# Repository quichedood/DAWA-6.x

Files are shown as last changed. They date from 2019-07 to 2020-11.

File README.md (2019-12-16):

# DAWA-6.x - FR (See below for US)

Site web officiel (FR) : http://dawa.panik-po.com/

DAWA est un système de chronométrage et d'acquisition de données pour votre moto.
Il enregistre les données 10x par seconde dans un fichier CSV.

# Q&A rapide
* __Comment sont récupérées les données ?__  
Pas de prise OBD, protocole trop lent sur ma "veille" moto de 2009. Je récupère les informations directement sur le faisceau du calculateur.
Chaque moto est différente, il faudra sur une autre moto :
    - Identifier les signaux (RPM, vitesse, position poignée de gaz, rapport engagé et frein)
    - Vérifier la forme des signaux (RPM = signal carré, poignée de gaz = signal analogique, etc.)
    - Eventuellement adapter le code au niveau de la programmation si le signal est complètement différent

* __Je peux l'assembler moi même ?__  
Aucun problème, attention néanmoins, il vous faut au minimum :
    - Le circuit imprimé (je peux le fournir, j'en ai quelques uns en stock)
    - Un programmateur pour les 2 µproc Atmel SAMD21 (Atmel ICE BASIC par exemple)
    - Une station de soudure à l'air chaud (indispensable pour souder l'IMU)

* __Combien ça coute ?__  
Grossièrement, voici ce que ça me coûte :
    - PCB : ~10€
    - Composants : ~90€
    - Autres (impression 3D, résine pour les sondes de t°, la journée passée à assembler un exemplaire) : à vous de juger

Certes, ça reste moins cher que ce que l'on peut trouver dans le commerce (Starlane, Alfano, 3DMS) mais ce n'est clairement pas comparable.  
Vous voulez un vrai chrono, utilisable à la sortie de sa boite, passez votre chemin et dirigez vous vers les produits du commerce.  
Vous voulez un maximum de fonctionnalités, pouvoir faire évoluer un projet libre et avez quelques notions en électronique/développement, ce projet est pour vous :)

# Les nouveautés de la v6
* __Nouveau circuit imprimé__ : DAWA v6 est désormais un circuit imprimé autonome (puce Atmel SAMD21 comme l'Arduino M0). La v5 était un module qui se branchait sur un Arduino M0
* __Nouveau capteur de position__ : Le capteurs 9 axes MPU-9250 est maintenant utilisé. Ce capteur est monté sur un circuit imprimé secondaire avec son propre µproc (Atmel SAMD21)
* __Nouvel écran OLED__ : Un peu plus grand (1.3" vs 0.96"). Le connecteur d’écran (SPI) est compatible avec les écrans LCD couleur 2,4" 240x320
* __Nouveau boitier__ : Un tout nouveau boîtier imprimé en 3D
* __Autodetection des capteurs__ : Les capteurs de température infrarouges sont maintenant détectés automatiquement
* __Navigation__ : Ajout d'un système de menu de navigation et 4 boutons pour permettre la configuration et l'utilisation sans smartphone ni Bluetooth
* __LEDs__ : Ajout de 4 LEDs pour des événements spécifiques (meilleur temps au tour par exemple)
* __Connecteurs__ : tous les connecteurs sont maintenant du même côté (en bas), le connecteur GPS est maintenant de type SMA (à visser)
* __Batterie GPS__ : Batterie rechargeable LIR 2025

# Quelles informations sont enregistrées ?
* __Acquisition de données bruts__ : Sur les motos Triumph et beaucoup d’autres, les valeurs du calculateur peuvent être lues directement (j’utilise personnellement: RPM, vitesse, position poignée de gaz, rapport engagé et frein)
* __Atitude de la moto__ : Un capteur à 9 axes (MPU-9250) est utilisé pour stocker les G et j'espère que bientôt, le roulis et le tangage
* __Position de la moto__ : Une puce GPS UBLOX 10Hz récupère les coordonnées GPS en temps réel
* __Température infrarouge__ : Vous pouvez brancher jusqu'à 6 capteurs de température infrarouge (pneus ou t° au sol, par exemple).
* __Entrées additionnelles__ : Vous pouvez mesurer 2 entrées analogiques et 2 entrées numériques supplémentaires (capteurs de suspension par exemple)

# Où est-ce enregistré ?
Tout est stocké sur une carte micro SD.  
10 fois par seconde, une nouvelle ligne est créée dans un fichier CSV. Cette ligne contient toutes les valeurs de données séparées par un point-virgule.  
Les valeurs actuelles sont affichées en temps réel sur l’écran OLED joint.

# Peut-il être utilisé comme un chronomètre ?
OUI ! Depuis la v4 et l'intégration d'une puce GPS 10Hz, des fonctions de chronométrage sont disponibles.

# Comment ça marche ?
Rien de plus simple !  
Un bouton pour démarrer l'enregistrement et un pour l'arrêter :)  
Un fichier CSV est créé à chaque nouvel enregistrement.  

# Qu'en est-il des fonctions de chronométrage
Un peu plus compliqué, vous devez mettre un fichier nommé "TRACKS.CSV" sur la carte SD.  
Ce fichier contiendra le nom du circuit et les coordonnées de la ligne d'arrivée, une ligne par circuit:  
`<trackname>;<finishline lat. A>;<finishline lon. A>;<finishline lat. B>;<finishline lon. B>`  
`CAROLE;489799930;25224350;489800230;25226330`  
Pour conserver la précision, la latitude et la longitude doivent être converties en nombres entiers (multiplier par 10 000 000).  
Au début de l’enregistrement, la piste la plus proche est automatiquement choisie.

# Vous avez dit Bluetooth?
La connexion Bluetooth est utile dans ces 2 cas:  
- Vous venez de terminer votre session sur piste et vous voulez connaître les temps/meilleurs tours  
- Avant d'utiliser DAWA, certains paramètres peuvent être ajustés, utilisez la console Bluetooth pour les configurer !  
  
J'utilise "Serial Bluetooth Terminal" sur Androïd. Connectez-vous et tapez "help" pour voir toutes les commandes disponibles

# Evolutions
* __Temps intermédiaire__ : Ajout de la gestion des temps intermédiaires

# Bugs connus
* __Angle d'inclinaison__ : Le composant est présent, l'algorithme aussi mais les valeurs dérivent dans le temps. C'est une problématique récurrente.

# Contenu du référentiel
* /3D Case - Pièces Fusion 360 et fichiers STL pour l'impression 3D
* /Arduino - Le fichier .ino que vous devez insérer dans l’Arduino M0
* /Documentation - Quelques informations sur ce projet (FR)
* /Eagle - Tous les fichiers Eagle (schémas, PCB/Gerber, bibliothèques, liste de composants)

# DAWA-6.x - US

French official website project : http://dawa.panik-po.com/

DAWA is an Arduino datalogger and laptimer for your motorbike.
It records 10 times per seconds in a CSV file lots of information.

# What's new in v6
* __New PCB__ : DAWA v6 is now a standalone PCB (Atmel SAMD21 chip like Arduino M0). v5 was a shield which needs an Arduino M0
* __New IMU__ : MPU-9250 is now used. This IMU is on a secondary PCB with his own µproc (Atmel SAMD21)
* __New OLED screen__ : A little bit bigger (1.3" vs 0.96"). The screen connector (SPI) is compatible with 2.4" 240x320 color LCD
* __New enclosure__ : A brand new 3D printed enclosure
* __Sensors autodetection__ : Infrared temperature sensors are now autodetected
* __Navigation__ : Add a navigation menu system and 4 buttons to allow configuration and use without smartphone and Bluetooth
* __Lights__ : Add 4 LEDS for specific events (best time on lap for example)
* __Connectors__ : All connectors are now on the same side (bottom), GPS connector is now SMA
* __GPS battery__ : Rechargeable LIR 2025 Battery

# What information is logged ?
* __Raw data acquisition__ : On Triumph bikes and many others, ECU values can be directly read (I personnaly use : RPM, SPEED, GEAR POSITION, THROTTLE and BRAKE state)
* __Environement values__ : A 9-axis sensor (MPU-9250) is used to store G-forces and I hope soon, roll and pitch
* __Position values__ : A UBLOX 10Hz GPS chip gets realtime coordinates
* __Infrared temperatures__ : You can plug up to 6 infrared temperature sensors (tyres or ground t° for example)
* __Additional inputs__ : You can measure 2 analog inputs and 2 digital inputs (suspension sensors for exemple)

# Where is it logged ?
Everything is stored on a micro SD card.  
10 times per seconds, a new line is created in a CSV file. This line contains every data values separated by a semicolon.  
Current values are displayed in realtime on the OLED screen attached.

# Could it be used as a laptimer ?
YES ! Since v4 and the integration of a 10Hz GPS chip, laptimer functions are available.

# How does it work ?
I couldn't make it easier !  
Press the button start recording, press again stop recording :)  
One CSV file is created on each new record.

# What about laptimer functions
A little bit more difficult, you have to put a file named "TRACKS.CSV" on the sdcard.  
This file will contain track name and finishline coordinates, one line per track :  
`<trackname>;<finishline lat. A>;<finishline lon. A>;<finishline lat. B>;<finishline lon. B>`  
`CAROLE;489799930;25224350;489800230;25226330`  
To keep precision, latitude and longitude should be converted to integers (multiply by 10 000 000).  
When start recording the closer track is automatically chosen.

# You said Bluetooth ?
Bluetooth connection is usefull in these 2 cases :
- You just finish your track session and want to know lap times / best lap
- Before using DAWA, some parameters could be adjusted, use the bluetooth console to setup them !

I'm using "Serial Bluetooth Terminal" on Androïd. Connect and type "help" to view all available commands

# What's next  
* __Laptimer split time__ : Add split time management

# Known bugs
* __Lean angle__ : Seems easy but in fact very complicated to obtain good values without drift

# Repository Contents
* /3D Case - Fusion 360 parts and STL files for 3D printing
* /Arduino - The .ino file you need to put in the Arduino M0
* /Documentation - Some brief explanations about this shield (french - not translated)
* /Eagle - All Eagle files (schematics, PCB/Gerber, libraries, parts list)

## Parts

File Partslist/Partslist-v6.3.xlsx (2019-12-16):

Qty | Value | Device | Package | Parts (Main boards) | Parts (MPU) | Description | Supplier | URL (for example) | Buy price (incl. Shipping) | Buy Qty | Unit Price | Total price
2 | MLX90614 BCC | MLX90614 BCC | TO-39 | MLX90614 BCC |  | Melexis IR Thermometer | ALIEXPRESS | https://www.aliexpress.com/item/32687163490.html?spm=a2g0o.cart.0.0.6e973c008PnrMs | 7.57 | 1 | 7.57 | 15.14
1 | UG-2864HSWEG01 | UG-2864HSWEG01 | 1X30-0.7MM | U$16 |  | UG-2864HSWEG01 OLED display | ALIEXPRESS | https://www.aliexpress.com/item/32955009400.html?spm=a2g0s.9042311.0.0.316a6c37wDnOT8 | 3.12 | 1 | 3.12 | 3.12
1 | NEO-M8 | NEO-M8 | NEO-M8 | U$3 |  | u-blox NEO GNSS module | ALIEXPRESS | https://www.aliexpress.com/item/32822645110.html?spm=a2g0s.9042311.0.0.27424c4dBywEPY | 14.64 | 1 | 14.64 | 14.64
2 | SN74LVC2G17DBVR | SN74LVC2G17DBVR | SOT95P280X145-6N | U12, U13 |  | DUAL SCHMITT-TRIGGER BUFFER | ALIEXPRESS | https://www.aliexpress.com/item/32955292314.html?spm=a2g0o.cart.0.0.55563c00YwAhGV | 9.76 | 50 | 0.1952 | 0.3904
4 | 10µF | CPOL-EUSMCB | SMC_B | C27, C29, C41 | C4 | POLARIZED CAPACITOR, European symbol | MOUSER | https://www.mouser.fr/ProductDetail/581-TAJB106K025RNJ | 0.407 | 1 | 0.407 | 1.628
1 | Power connector | NOT ON PCB | NOT ON PCB | NOT ON PCB |  |  | ALIEXPRESS | https://www.aliexpress.com/item/32820917628.html?spm=a2g0s.9042311.0.0.27424c4diOwAsr | 1.43 | 2 | 0.715 | 0.715
2 | OSCILLATOR_32KHZ | OSCILLATOR_32KHZ | OSCILLATOR_SMD | U$1, U$14 |  | CM7V-T1A Tuning Fork Crystal 32.768 kHz | MOUSER | https://www.mouser.fr/ProductDetail/428-200458-MG01 | 0.385 | 1 | 0.385 | 0.77
1 | GPS antenna | NOT ON PCB | NOT ON PCB | NOT ON PCB |  |  | ALIEXPRESS | https://www.aliexpress.com/item/32631796141.html?spm=a2g0s.9042311.0.0.27424c4d7JbT8R | 2.69 | 1 | 2.69 | 2.69
14 | 4.7k | R-EU_R0603 | R0603 | R13, R17, R18, R21, R22, R25, R49, R50 | R3, R4, R7, R8 | RESISTOR, European symbol | ALIEXPRESS | * | 1 | 100 | 0.01 | 0.14
4 | SKPMAPE10 | SKPMAPE10 | SKPMAPE10 | U$5, U$6, U$7, U$8 |  | Softtouch buttons | ALIEXPRESS | https://www.aliexpress.com/item/32704068968.html?spm=a2g0s.9042311.0.0.68254c4dGCYlrO | 2.26 | 10 | 0.226 | 0.904
5 | P82B96D | P82B96D | SOIC127P600X175-8N | U5, U9, U10 | U3 | DUAL BIDIRECTIONAL BUS BUFFER | ALIEXPRESS | https://www.aliexpress.com/item/32913502650.html?spm=a2g0s.9042311.0.0.27424c4dXN6ine | 15.16 | 20 | 0.758 | 3.79
1 | ATSAMD51G19A_TQFN48 | ATSAMD51G19A_TQFN48 | TQFN-48 |  | U1 | Atmel SAMD51G19A SMART ARM-Based Microcontroller | MOUSER | https://www.mouser.fr/ProductDetail/556-ATSAMD51G19AMUT | 10.77 | 3 | 3.59 | 3.59
1 | MS5637_MS5637 | MS5637_MS5637 | MS5637_MS5637 |  | U4 | Barometric sensor | MOUSER | https://www.mouser.fr/ProductDetail/824-MS563702BA03-50 | 10.9 | 5 | 2.18 | 2.18
2 | MCP23017SS | MCP23017SS | SSOP28 | IC1, IC6 |  |  | MOUSER | https://www.mouser.fr/ProductDetail/579-MCP23017-E-SS | 1.13 | 1 | 1.13 | 2.26
1 | HM-11 | HM-11 | HM-11 | U$2 |  | JNHuaMao HM-11 Bluetooth 4.0 Transceiver | ALIEXPRESS | https://www.aliexpress.com/item/32228842714.html?spm=a2g0s.9042311.0.0.27424c4d7JbT8R | 4.16 | 1 | 4.16 | 4.16
1 | SMA connector | SMACONNECTOR_EDGE | SMA_EDGELAUNCH | X1 |  | SMA Connector | ALIEXPRESS | https://www.aliexpress.com/item/32779564868.html?spm=a2g0s.9042311.0.0.27424c4d7JbT8R | 1.72 | 10 | 0.172 | 0.172
2 | 24AA02E48 | 24AA00OT | SOT23-5L | IC3 | IC1 | Serial EEPROM | MOUSER | https://www.mouser.fr/ProductDetail/579-24AA02E48TIOT | 0.198 | 1 | 0.198 | 0.396
2 | Micro USB connector | USB | USB-MINIB-DAWA | CN1 | CN1 | USB Connectors | ALIEXPRESS | https://www.aliexpress.com/item/32694652292.html?spm=a2g0s.9042311.0.0.27424c4d0a2JnM | 0.82 | 20 | 0.041 | 0.082
1 | LM2734Y | LM2734Y | SOT23-6 | IC2 |  |  | ALIEXPRESS | https://www.aliexpress.com/item/32790388586.html?spm=a2g0s.9042311.0.0.27424c4dXyVsTd | 3.56 | 10 | 0.356 | 0.356
1 | MCP73831/OT | MCP73831/OT | SOT23-5L | IC5 |  | MCP73831/2 | ALIEXPRESS | https://www.aliexpress.com/item/32945891297.html?spm=a2g0s.9042311.0.0.27424c4dlCWdv3 | 2.59 | 20 | 0.1295 | 0.1295
1 | LMV321M5 | LMV321M5 | SOT23-5 | IC7 |  | General Purpose, Low Voltage, Rail-to-Rail Output Operational Amplifiers | MOUSER | https://www.mouser.fr/ProductDetail/926-LMV321M5X-NOPB | 0.716 | 1 | 0.716 | 0.716
2 | PINHEAD_PINHD-2X5PASSO127 | PINHEAD_PINHD-2X5PASSO127 | PINHEAD_2X05_127 | JTAG | JTAG1 | PIN HEADER | ALIEXPRESS | https://www.aliexpress.com/item/32795241952.html?spm=a2g0s.9042311.0.0.27424c4dXyVsTd | 7.17 | 100 | 0.0717 | 0.1434
3 | MH2029-300Y | WE-CBF_0805 | 0805 | L1, L6 | L3 | SMD EMI Suppression Ferrite Beads | MOUSER | https://www.mouser.fr/ProductDetail/652-MH2029-300Y | 0.049 | 1 | 0.049 | 0.147
1 | 27nH | L_0603 | L0603 | L2 |  | INDUCTOR | MOUSER | https://www.mouser.fr/ProductDetail/81-LQG18HN27NJ00D | 0.158 | 1 | 0.158 | 0.158
1 | 10u SRR0604-100ML | L-USSRR0604 | SRR0604 | L4 |  | INDUCTOR, American symbol | MOUSER | https://www.mouser.fr/ProductDetail/652-SRR0604-100ML | 0.473 | 1 | 0.473 | 0.473
1 | PCB kit | NOT ON PCB | NOT ON PCB | NOT ON PCB |  | All PCB for DAWA (2 infrared temperature sensor) | JLCPCB | N/A | 104 | 10 | 10.4 | 10.4
2 | 47µF | CPOL-EUD | PANASONIC_D | PC1, PC2 |  | POLARIZED CAPACITOR, European symbol | MOUSER | https://www.mouser.fr/ProductDetail/667-EEE-HC1E470XP | 0.11 | 1 | 0.11 | 0.22
1 | LI_3.6 | LI_3.6 | LI_3.6 | U$17 |  | Battery | ALIEXPRESS | https://www.aliexpress.com/item/32829778871.html?spm=a2g0s.9042311.0.0.27424c4dNNMwNQ | 16.94 | 10 | 1.694 | 1.694
1 | RJ45X8 | RJ45X8 | RJ45X8 | U$18 |  |  | ALIEXPRESS | https://www.aliexpress.com/item/32274753116.html?spm=a2g0s.9042311.0.0.5e5f4c4dSjd4JF | 17.46 | 10 | 1.746 | 1.746
2 | 4_PIN_JST-XH-SMD | 4_PIN_JST-XH-SMD | 4_PIN_JST-XH-SMD | U$9, U$15 |  | Inputs connectors (2M) | ALIEXPRESS | https://www.aliexpress.com/item/33012426179.html?spm=a2g0o.cart.0.0.3db13c00PXhM7w | 0.77 | 20 | 0.0385 | 0.077
1 | CD40106BPW | CD40106BPW | SOP65P640X120-14N | U14 |  | QUADRUPLE FET BUS SWITCH 2.5-V/3.3-V | MOUSER | https://www.mouser.fr/ProductDetail/595-CD40106BPWR | 0.276 | 1 | 0.276 | 0.276
1 | 74AHC1G125 | 74AHC1G125DBV | SOT23-5 | U3 |  | TRI-STATE SINGLE BUSS BUFFER | MOUSER | https://www.mouser.fr/ProductDetail/595-SN74AHC1G125DBVR | 0.237 | 1 | 0.237 | 0.237
1 | TLV2374 | TLV2374IPWR | SOP65P640X120-14N | U8 |  | OPERATIONAL AMPLIFIERS | ALIEXPRESS | https://www.aliexpress.com/item/32802912865.html?spm=a2g0s.9042311.0.0.27424c4d7JbT8R | 7.73 | 10 | 0.773 | 0.773
2 | 4_PIN_JST-XH-SMD | 4_PIN_JST-XH-SMD | 4_PIN_JST-XH-SMD |  |  | Inputs connectors (2F) | ALIEXPRESS | https://www.aliexpress.com/item/32832523571.html?spm=a2g0o.cart.0.0.3db13c00PXhM7w | 1.47 | 20 | 0.0735 | 0.147
1 | PRTR5V0U2X | PRTR5V0U2X | SOT-143B | U2 |  | I2C-Bus EDS Protection | ALIEXPRESS | https://www.aliexpress.com/item/32915507427.html?spm=a2g0s.9042311.0.0.27424c4dXyVsTd | 1.31 | 10 | 0.131 | 0.131
1 | AP2112K-3.3 | VREG_SOT23-5 | SOT23-5 |  | U5 | SOT23-5 Fixed Voltage Regulators | ALIEXPRESS | https://www.aliexpress.com/item/32884059737.html?spm=a2g0s.9042311.0.0.27424c4d7JbT8R | 1.67 | 10 | 0.167 | 0.167
33 | 100nF | C-EUC0603 | C0603 | C1, C2, C5, C7, C12, C13, C16, C17, C20, C25, C28, C30, C36, C38, C40, C9, C11, C15, C19, C24, C35, C47, C48, C51, C56, C57, C58 | C2, C3, C5, C10, C11, C12 | CAPACITOR, European symbol | ALIEXPRESS | * | 1 | 100 | 0.01 | 0.33
1 | CD1206-S01575 | DIODE-MINIMELF | MINIMELF | D3 |  | DIODE | MOUSER | https://www.mouser.fr/ProductDetail/652-CD1206-S01575 | 0.113 | 1 | 0.113 | 0.113
1 | ATSAMD21G-A | ATSAMD21G-A | TQFP-48 | U1 |  | Atmel SAMD21G SMART ARM-Based Microcontroller | MOUSER | https://www.mouser.fr/ProductDetail/556-ATSAMD21G18A-AU | 2.75 | 1 | 2.75 | 2.75
7 | 10k | R-EU_R0603 | R0603 | R2, R3, R4, R5, R8, R9 | R1 | RESISTOR, European symbol | ALIEXPRESS | * | 1 | 100 | 0.01 | 0.07
1 | MPU-9250 | MPU-9250 | QFN24_PAD |  | U2 | NC pin 19. 2-6 & 14-17 not internally connected. May be used for PCB trace routing. | ALIEXPRESS | https://www.aliexpress.com/item/32376850604.html?spm=a2g0s.9042311.0.0.27424c4dNNMwNQ | 14.83 | 5 | 2.966 | 2.966
6 | LEDCHIPLED_1206 | LEDCHIPLED_1206 | CHIPLED_1206 | LED1, LED2, LED3, LED4 | LED1, LED6 | LED | ALIEXPRESS | * | 1 | 100 | 0.01 | 0.06
1 | FDN340P | PMOSSOT23 | SOT-23 | T1 |  | MOS FET | ALIEXPRESS | https://www.aliexpress.com/item/32728160713.html?spm=a2g0s.9042311.0.0.27424c4dXyVsTd | 1.53 | 20 | 0.0765 | 0.0765
5 | 2.2µF | C-EUC0603 | C0603 | C37, C49, C52, C53, C55 |  | CAPACITOR, European symbol | ALIEXPRESS | * | 1 | 100 | 0.01 | 0.05
3 | MBR120 | DIODE_SOD-123FL | SOD-123FL | D2, D5 | D1 | Diode | ALIEXPRESS | https://www.aliexpress.com/item/20PCS-MBR120VLSFT1G-MBR120-DIODE-SCHOTTKY-20V-1A-SOD123FL-MBR120LSFT1G/32658704895.html | 3.82 | 20 | 0.191 | 0.573
1 | MF-MSMF050-2 500mA | L-EUL1812 | L1812 | F1 |  | INDUCTOR, European symbol | ALIEXPRESS | https://www.aliexpress.com/item/32842202101.html?spm=a2g0s.9042311.0.0.27424c4dXyVsTd | 1.2 | 20 | 0.06 | 0.06
1 | NCP1117ST33T3G-3V3 | MC33269ST-3.3T3 | SOT223 | IC4 |  | Adjustable Output Low Dropout Voltage Regulator 800 mA | ALIEXPRESS | https://www.aliexpress.com/item/32987702593.html?spm=a2g0o.cart.0.0.13c93c00cd9LSJ | 2.86 | 1 | 2.86 | 2.86
1 | DM3AT-SF-PEJM5 | DM3AT-SF-PEJM5 | DM3AT-SF-PEJM5 | J1 |  | CONN MICRO SD R/A PUSH-PUSH SMD | ALIEXPRESS | https://www.aliexpress.com/item/32239137511.html?spm=a2g0s.9042311.0.0.27424c4dzM3I7q | 12.85 | 20 | 0.6425 | 0.6425
1 | PINHD-1X14-CB | PINHD-1X14-CB | 1X14-CB | JP2 |  | PIN HEADER | ALIEXPRESS | https://www.aliexpress.com/item/32759414721.html?spm=a2g0s.9042311.0.0.27424c4d0jrmnK | 3.41 | 10 | 0.341 | 0.341
4 | 10µF | C-EUC0603 | C0603 | C26 | C1, C7, C8 | CAPACITOR, European symbol | ALIEXPRESS | * | 1 | 100 | 0.01 | 0.04
4 | 22pF | C-EUC0603 | C0603 | C3, C4, C33, C34 |  | CAPACITOR, European symbol | ALIEXPRESS | * | 1 | 100 | 0.01 | 0.04
4 | 470pF | C-EUC0603 | C0603 | C43, C44, C45, C46 |  | CAPACITOR, European symbol | ALIEXPRESS | * | 1 | 100 | 0.01 | 0.04
4 | 3mm hole PCB spacer | NOT ON PCB | NOT ON PCB | NOT ON PCB |  | 3mm hole PCB spacer | ALIEXPRESS | https://www.aliexpress.com/item/32320716046.html?spm=a2g0s.9042311.0.0.27426c37aIuRJm | 2.49 | 100 | 0.0249 | 0.0996
4 | 1k | R-EU_R0603 | R0603 | R15, R16, R53, R54 |  | RESISTOR, European symbol | ALIEXPRESS | * | 1 | 100 | 0.01 | 0.04
3 | 4.7µF | C-EUC0603 | C0603 | C6, C8, C23 |  | CAPACITOR, European symbol | ALIEXPRESS | * | 1 | 100 | 0.01 | 0.03
3 | 100k | R-EU_R0603 | R0603 | R6, R7 | R6 | RESISTOR, European symbol | ALIEXPRESS | * | 1 | 100 | 0.01 | 0.03
1 | RJ45 | RJ45 | RJ45 | RJ45_MAIN_BOARD |  |  | ALIEXPRESS | https://www.aliexpress.com/item/2002442142.html?spm=a2g0s.9042311.0.0.27424c4dkcI8bP | 1.7 | 10 | 0.17 | 0.17
2 | 10nF | C-EUC0603 | C0603 | C31, C42 |  | CAPACITOR, European symbol | ALIEXPRESS | * | 1 | 100 | 0.01 | 0.02
2 | 330 | R-EU_R0603 | R0603 | R12, R24 |  | RESISTOR, European symbol | ALIEXPRESS | * | 1 | 100 | 0.01 | 0.02
2 | 1.8k | R-EU_R0603 | R0603 | R51, R52 |  | RESISTOR, European symbol | ALIEXPRESS | * | 1 | 100 | 0.01 | 0.02
2 | 510 | 742-8_SNS | 742-8NS | RN2, RN7 |  | CTS 742 Series | ALIEXPRESS | * | 1 | 100 | 0.01 | 0.02
2 | 10k | 742-8_SNS | 742-8NS | RN3, RN4 |  | CTS 742 Series | ALIEXPRESS | * | 1 | 100 | 0.01 | 0.02
2 | 1µF | C-EUC0603 | C0603 |  | C6, C9 | CAPACITOR, European symbol | ALIEXPRESS | * | 1 | 100 | 0.01 | 0.02
2 | 100 | R-EU_R0603 | R0603 |  | R2, R5 | RESISTOR, European symbol | ALIEXPRESS | * | 1 | 100 | 0.01 | 0.02
2 | MOMENTARY-SWITCH-SPST-SMD-6.0X3.5MM | MOMENTARY-SWITCH-SPST-SMD-6.0X3.5MM | TACTILE_SWITCH_SMD_6.0X3.5MM |  | S1, S2 | Momentary Switch (Pushbutton) - SPST | ALIEXPRESS | https://www.aliexpress.com/item/50Pcs-High-Quality-3-6-2-5mm-SMD-orange-white-red-blue-yellow-brown-black-green/32853551467.html | 2.74 | 50 | 0.0548 | 0.1096
1 | 47pF | C-EUC0603 | C0603 | C10 |  | CAPACITOR, European symbol | ALIEXPRESS | * | 1 | 100 | 0.01 | 0.01
1 | 52k3 | R-EU_R0603 | R0603 | R10 |  | RESISTOR, European symbol | MOUSER | https://www.mouser.fr/ProductDetail/71-CRCW0603-52.3K | 0.059 | 1 | 0.059 | 0.059
1 | 10 | R-EU_R0603 | R0603 | R11 |  | RESISTOR, European symbol | ALIEXPRESS | * | 1 | 100 | 0.01 | 0.01
1 | 27k | R-EU_R0603 | R0603 | R14 |  | RESISTOR, European symbol | ALIEXPRESS | * | 1 | 100 | 0.01 | 0.01
1 | 100 | 742-8_SNS | 742-8NS | RN1 |  | CTS 742 Series | ALIEXPRESS | * | 1 | 100 | 0.01 | 0.01
1 | 4.7k | 742-8NS | 742-8NS | RN5 |  | CTS 742 Series | ALIEXPRESS | * | 1 | 100 | 0.01 | 0.01
1 | 9.1k | 742-8NS | 742-8NS | RN6 |  | CTS 742 Series | ALIEXPRESS | * | 1 | 100 | 0.01 | 0.01
1 | 390k | R-EU_R0603 | R0603 | R1 |  | RESISTOR, European symbol | ALIEXPRESS | * | 1 | 100 | 0.01 | 0.01
3 | RJ45 cables (0,5+1+2m) | NOT ON PCB | NOT ON PCB | NOT ON PCB |  |  | ALIEXPRESS | * | 12 | 10 | 1.2 | 3.6
1 | Enclosure kit | NOT ON PCB | NOT ON PCB | NOT ON PCB |  | 3D Printed with PETG | HOMEMADE | N/A | 5 | 1 | 5 | 5
1 | Atmel ICE BASIC | NOT ON PCB | NOT ON PCB | NOT ON PCB |  | You need it to first flash Arduino bootloader on SAMD21 (or you need to buy SAMD21 with bootloader on it !) | MOUSER | https://www.mouser.fr/ProductDetail/556-ATATMELICE-BASIC | 0 | 1 | 0 | 0
 |  |  |  |  |  |  |  |  |  |  |  | 95.1185

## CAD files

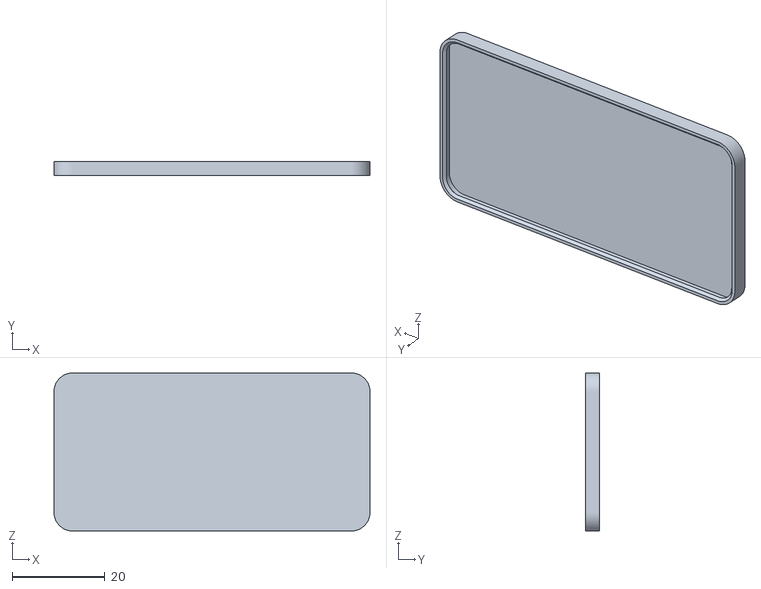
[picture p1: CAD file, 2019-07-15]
Main boards/3D Case/DAWA 6.1-SWITCH-ENCLOSURE2.stl
68.0 x 3.00 x 34.0

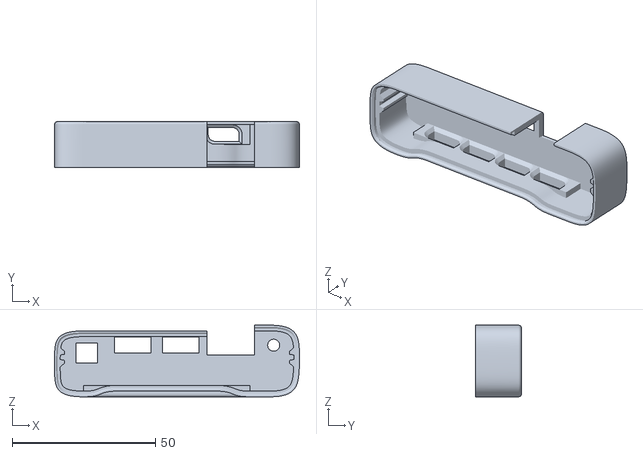
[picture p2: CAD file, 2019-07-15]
Main boards/3D Case/DAWA 6.1-ENCLOSURE2.stl
85.5 x 16.0 x 25.0

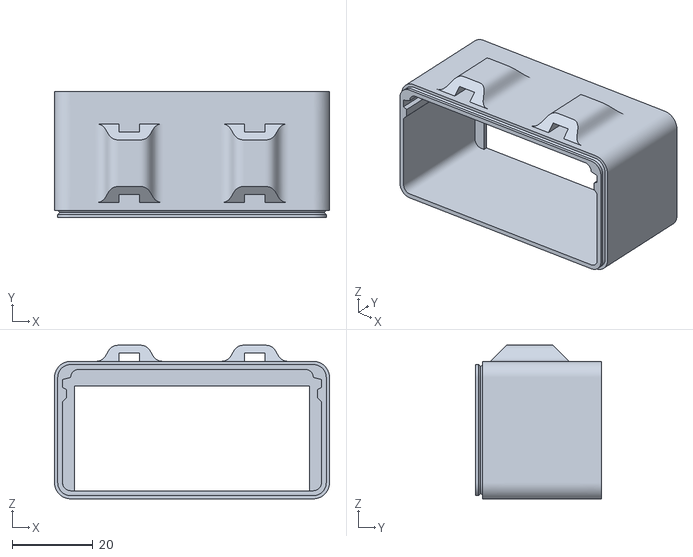
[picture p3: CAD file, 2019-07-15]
Main boards/3D Case/DAWA 6.1-SWITCH-ENCLOSURE1.stl
68.0 x 31.2 x 38.0

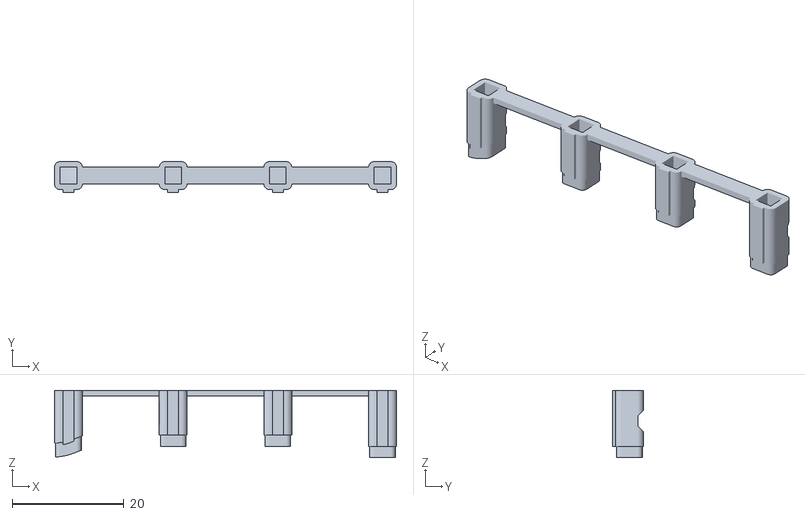
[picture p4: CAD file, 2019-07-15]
Main boards/3D Case/DAWA 6.1-ENCLOSURE4-LIGHTS.stl
61.2 x 5.50 x 12.0

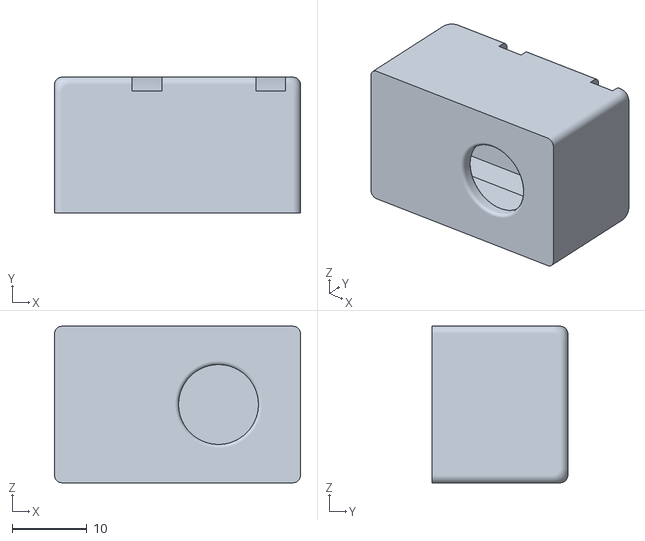
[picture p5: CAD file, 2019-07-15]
Main boards/3D Case/DAWA 6.1-MLX.stl
33.0 x 18.2 x 21.0

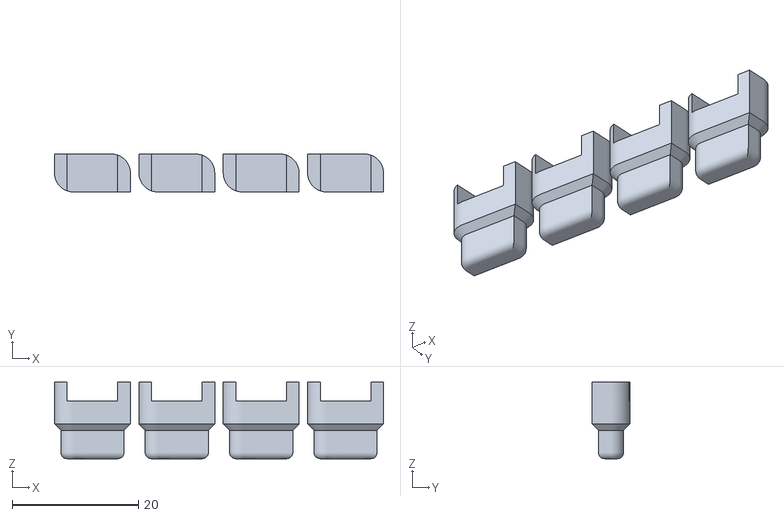
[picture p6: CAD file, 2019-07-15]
Main boards/3D Case/DAWA 6.1-ENCLOSURE3-BUTTONS.stl
52.0 x 6.00 x 12.1

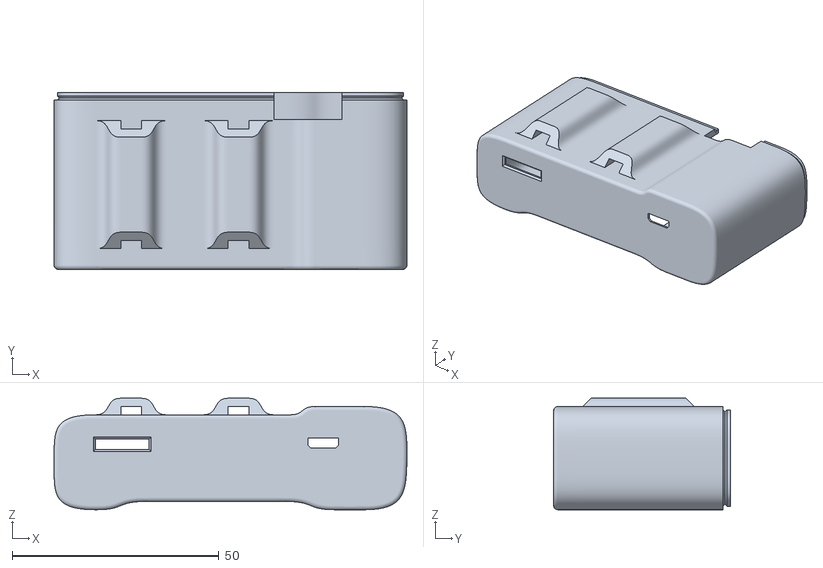
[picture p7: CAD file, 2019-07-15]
Main boards/3D Case/DAWA 6.1-ENCLOSURE1.stl
85.5 x 42.8 x 27.0

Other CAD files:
Main boards/3D Case/DAWA 6.1-ENCLOSURE.f3d
Main boards/3D Case/DAWA 6.1-MLX.f3d
Main boards/3D Case/DAWA 6.1-SWITCH.f3d

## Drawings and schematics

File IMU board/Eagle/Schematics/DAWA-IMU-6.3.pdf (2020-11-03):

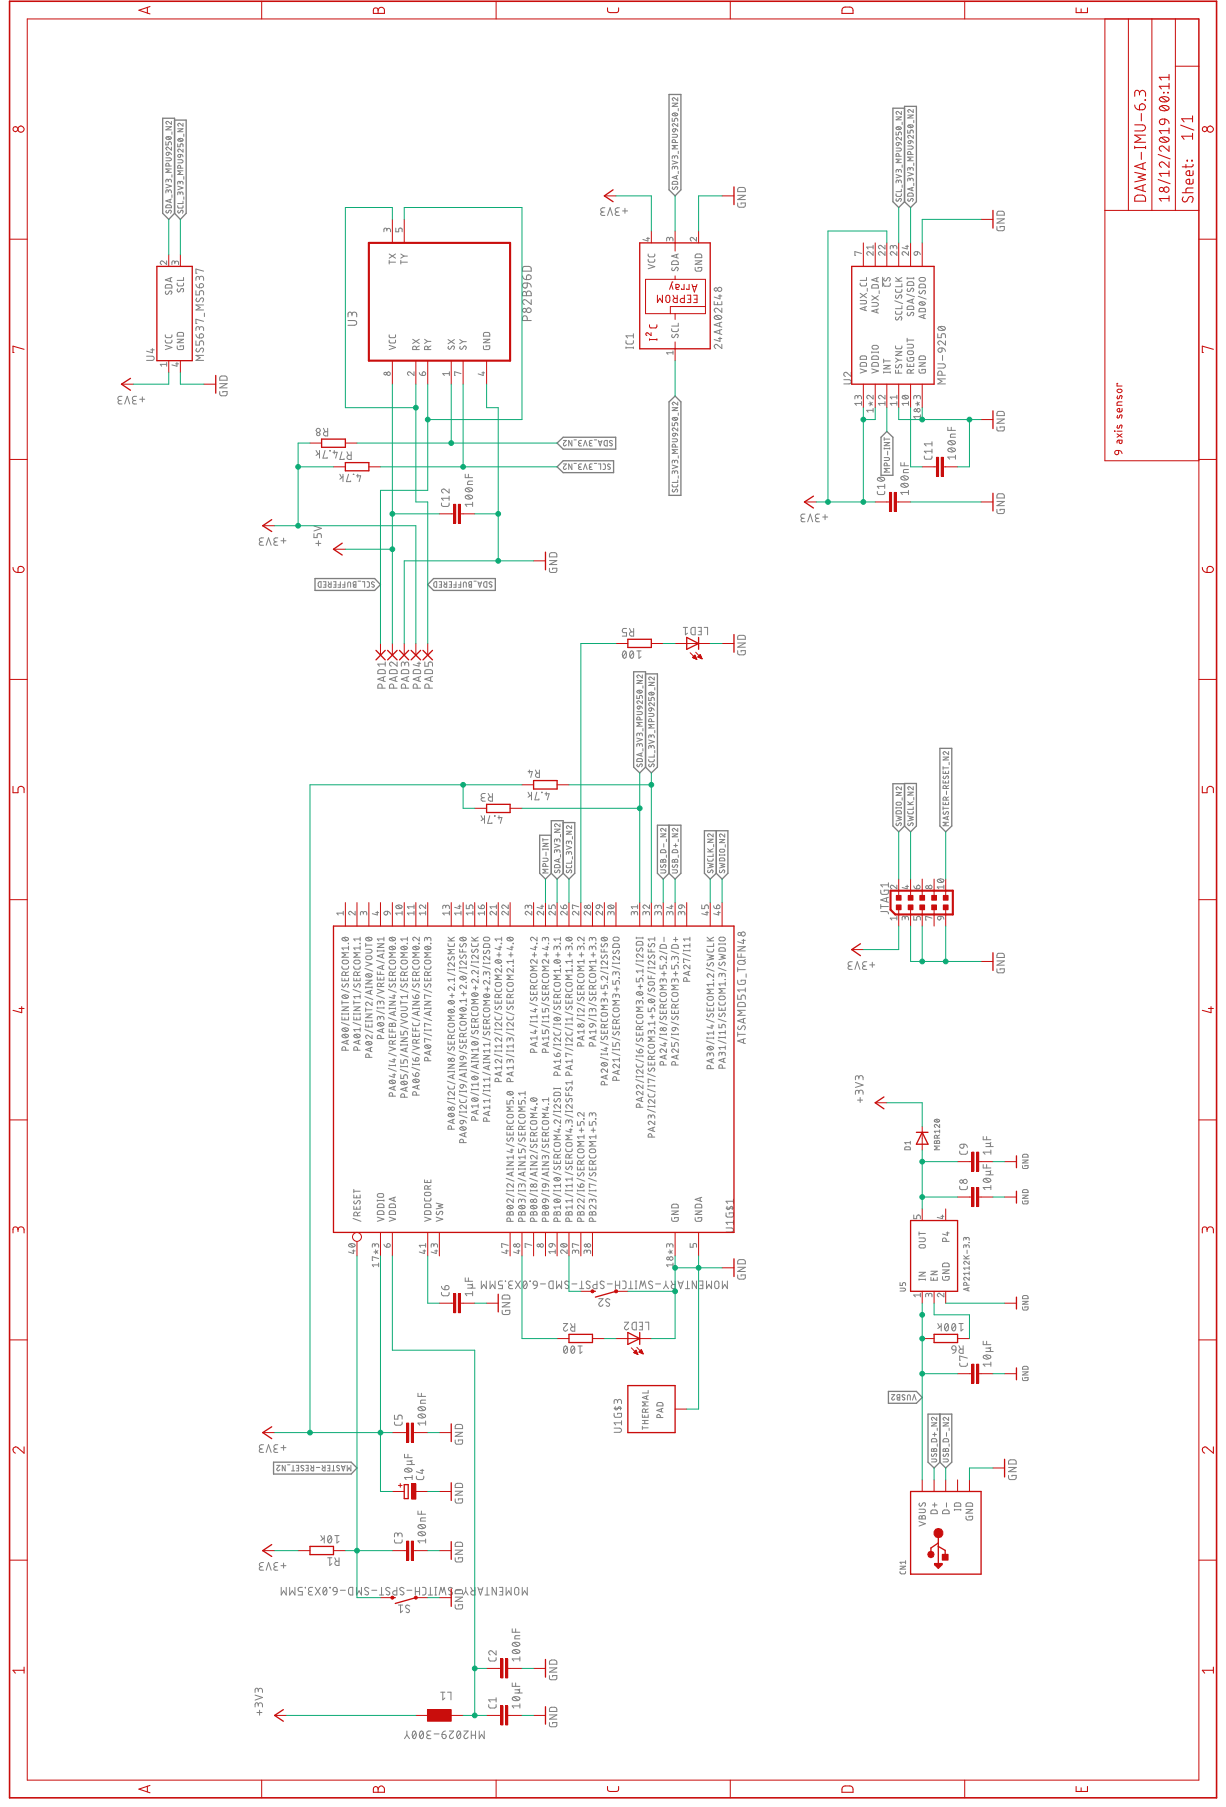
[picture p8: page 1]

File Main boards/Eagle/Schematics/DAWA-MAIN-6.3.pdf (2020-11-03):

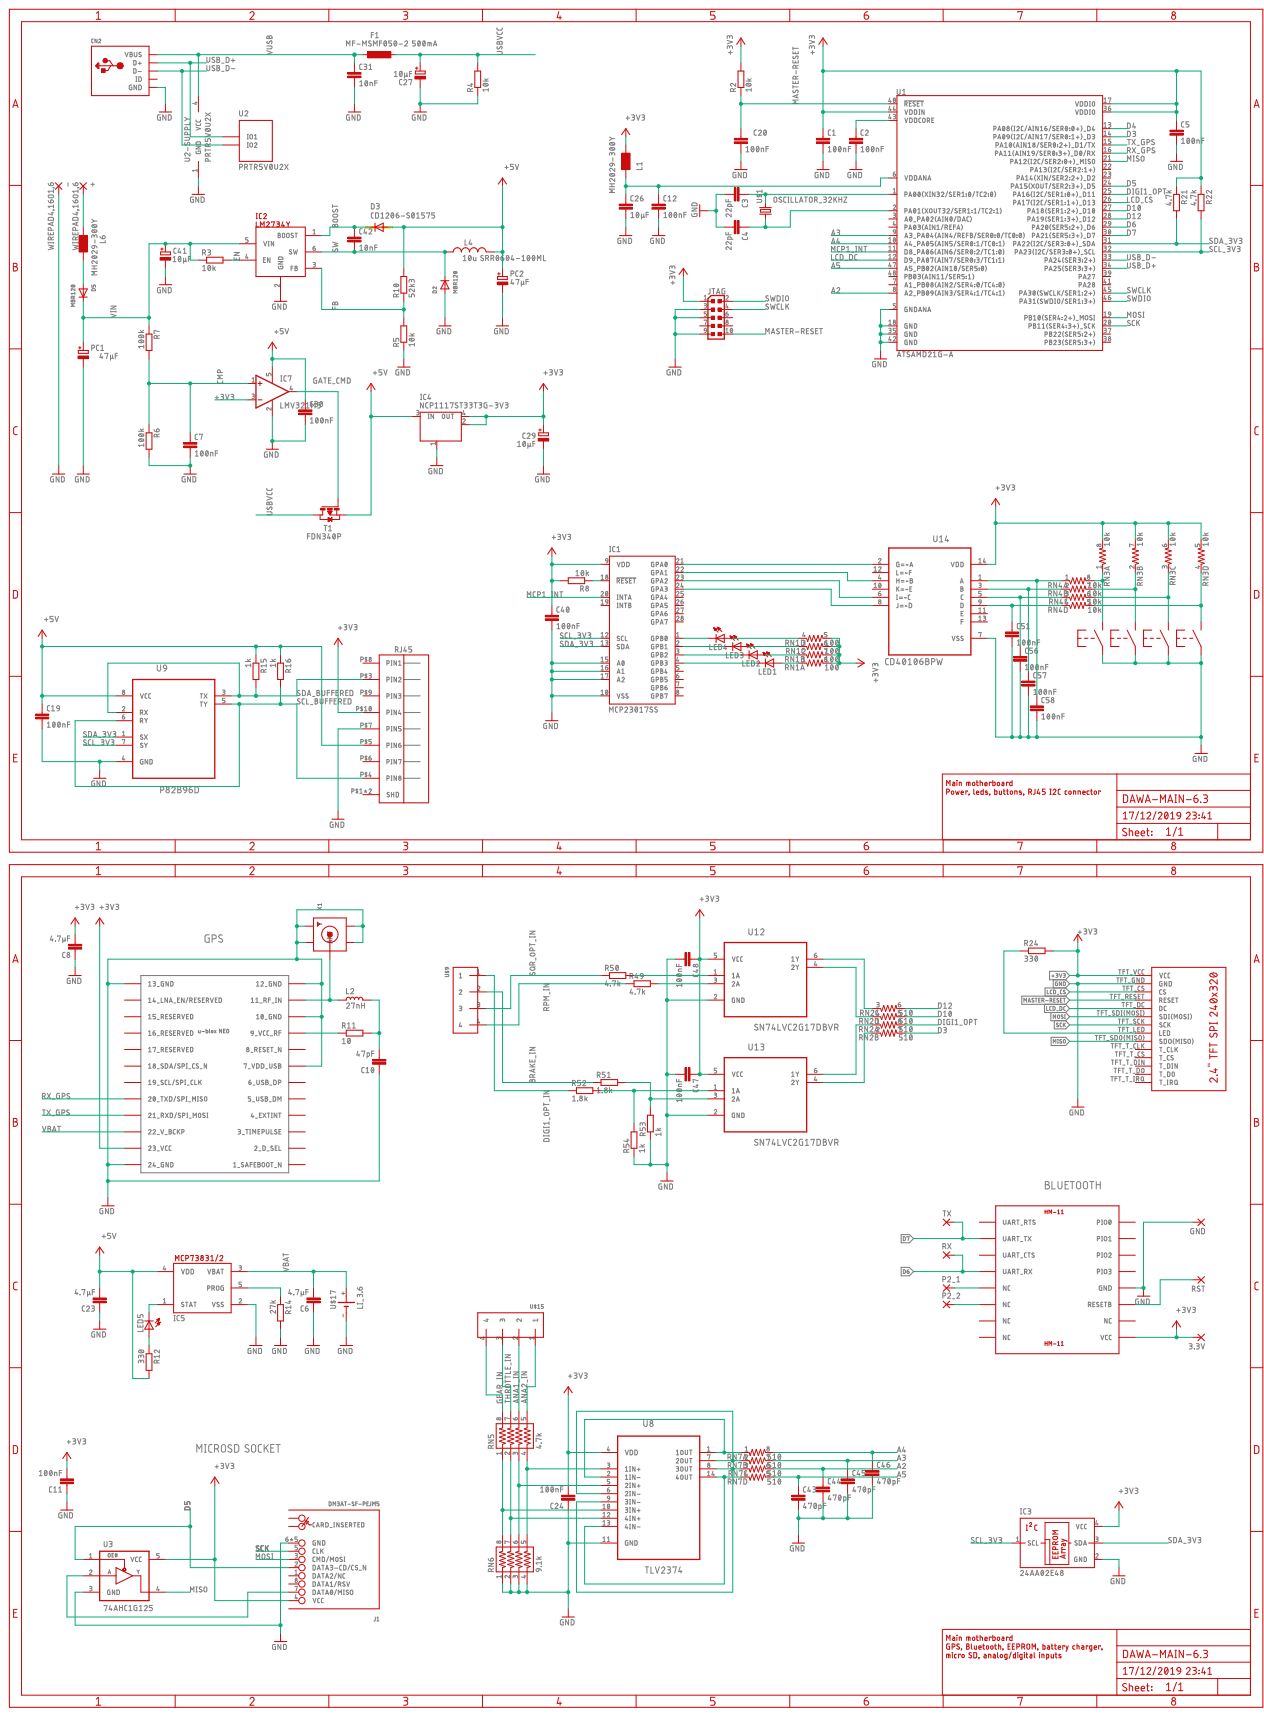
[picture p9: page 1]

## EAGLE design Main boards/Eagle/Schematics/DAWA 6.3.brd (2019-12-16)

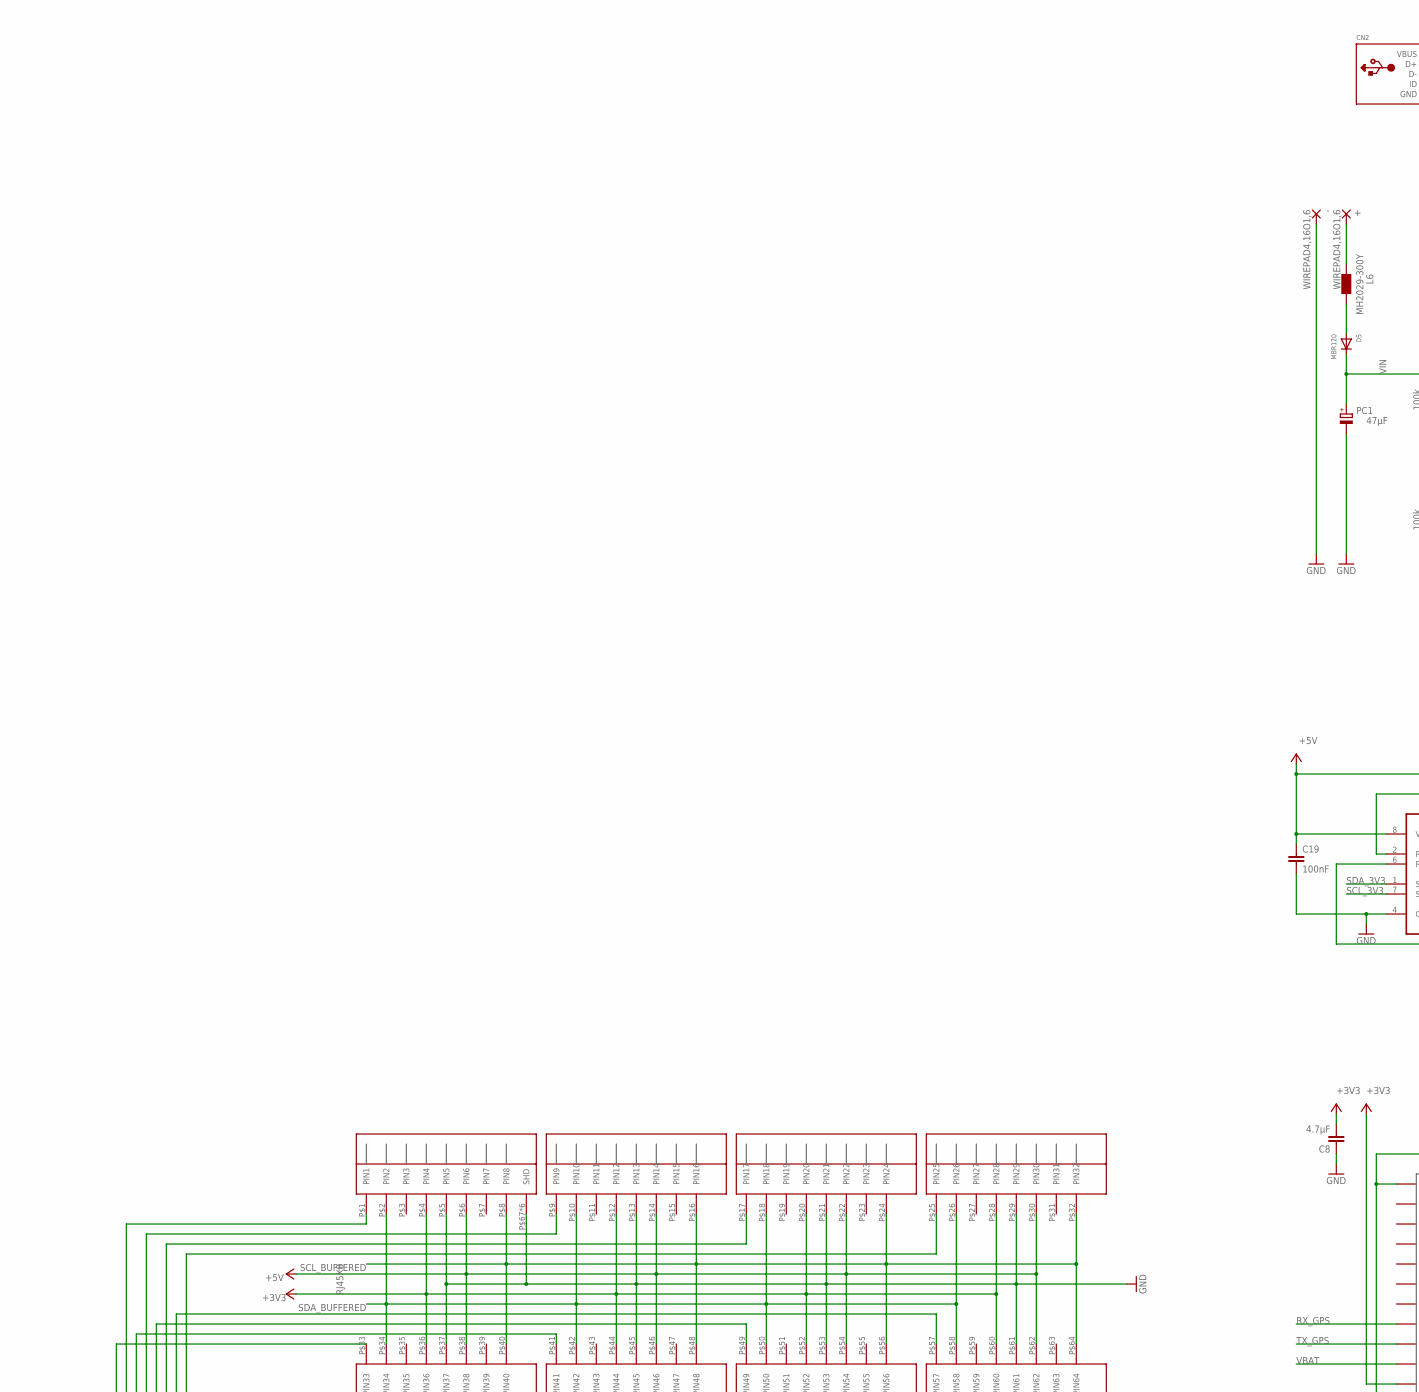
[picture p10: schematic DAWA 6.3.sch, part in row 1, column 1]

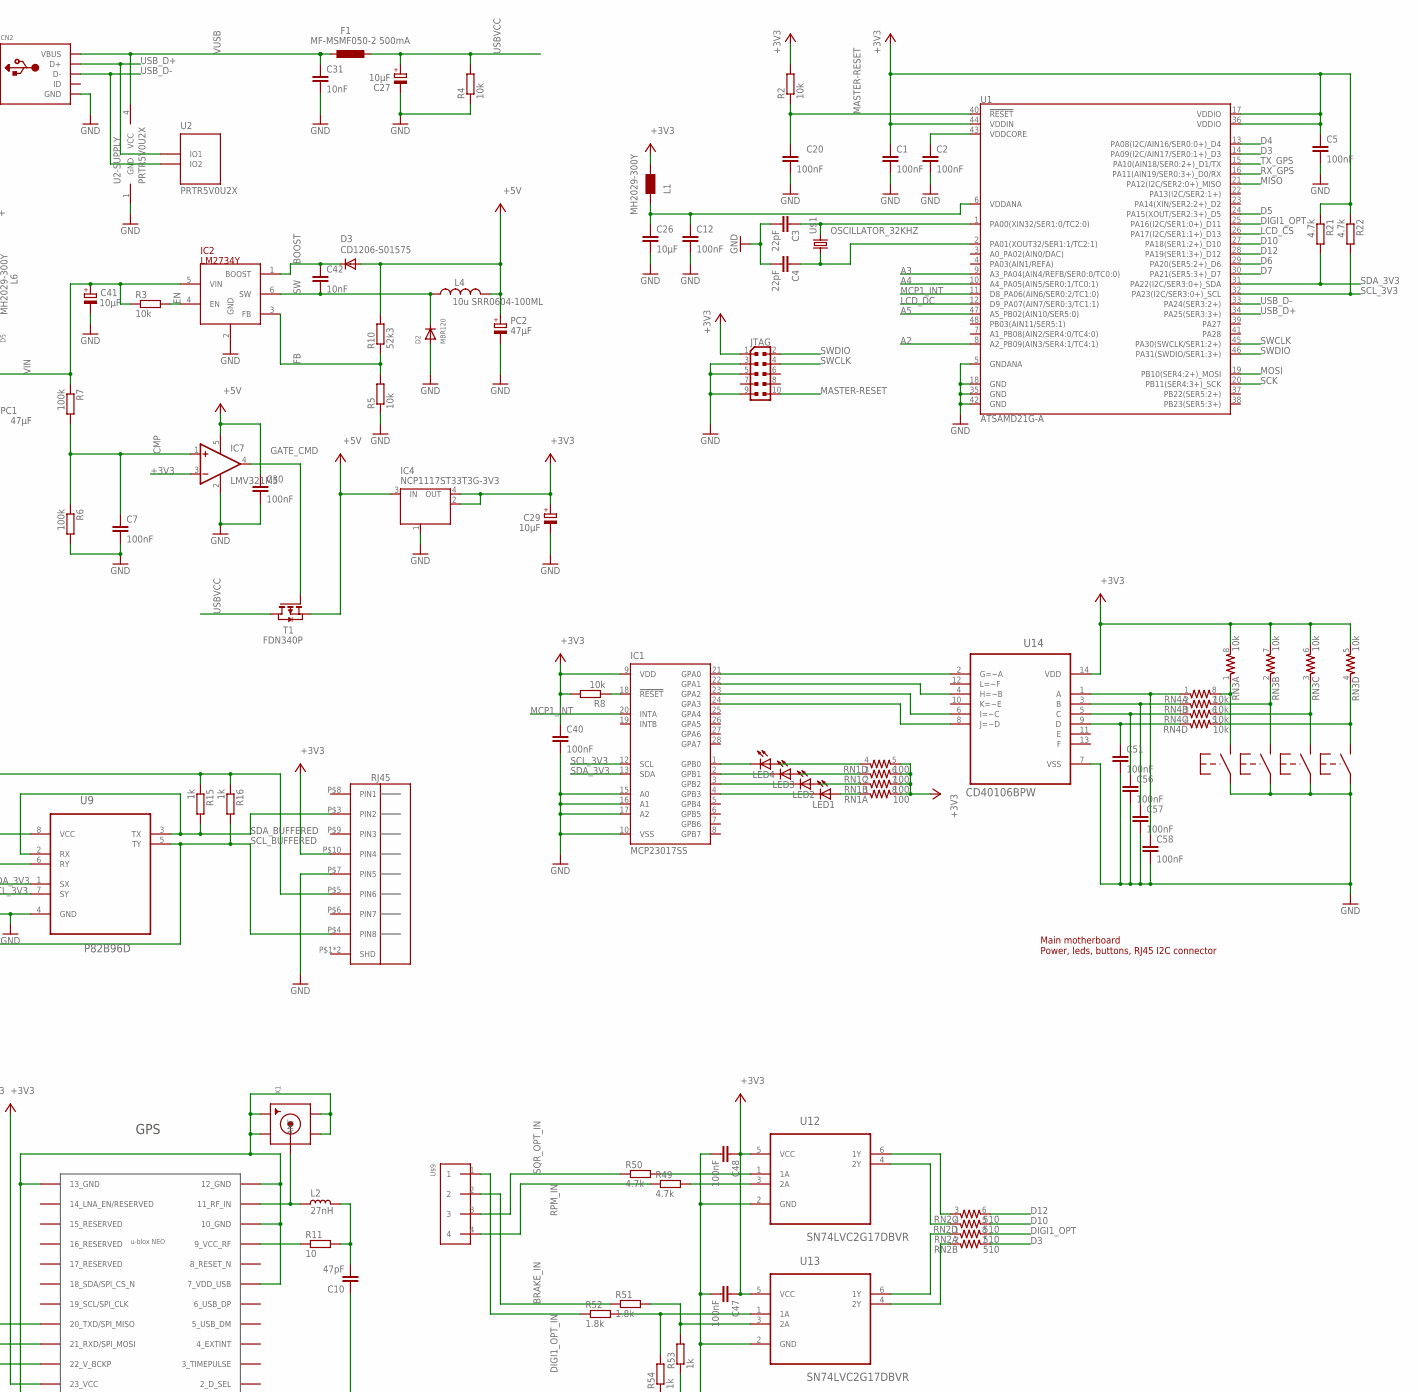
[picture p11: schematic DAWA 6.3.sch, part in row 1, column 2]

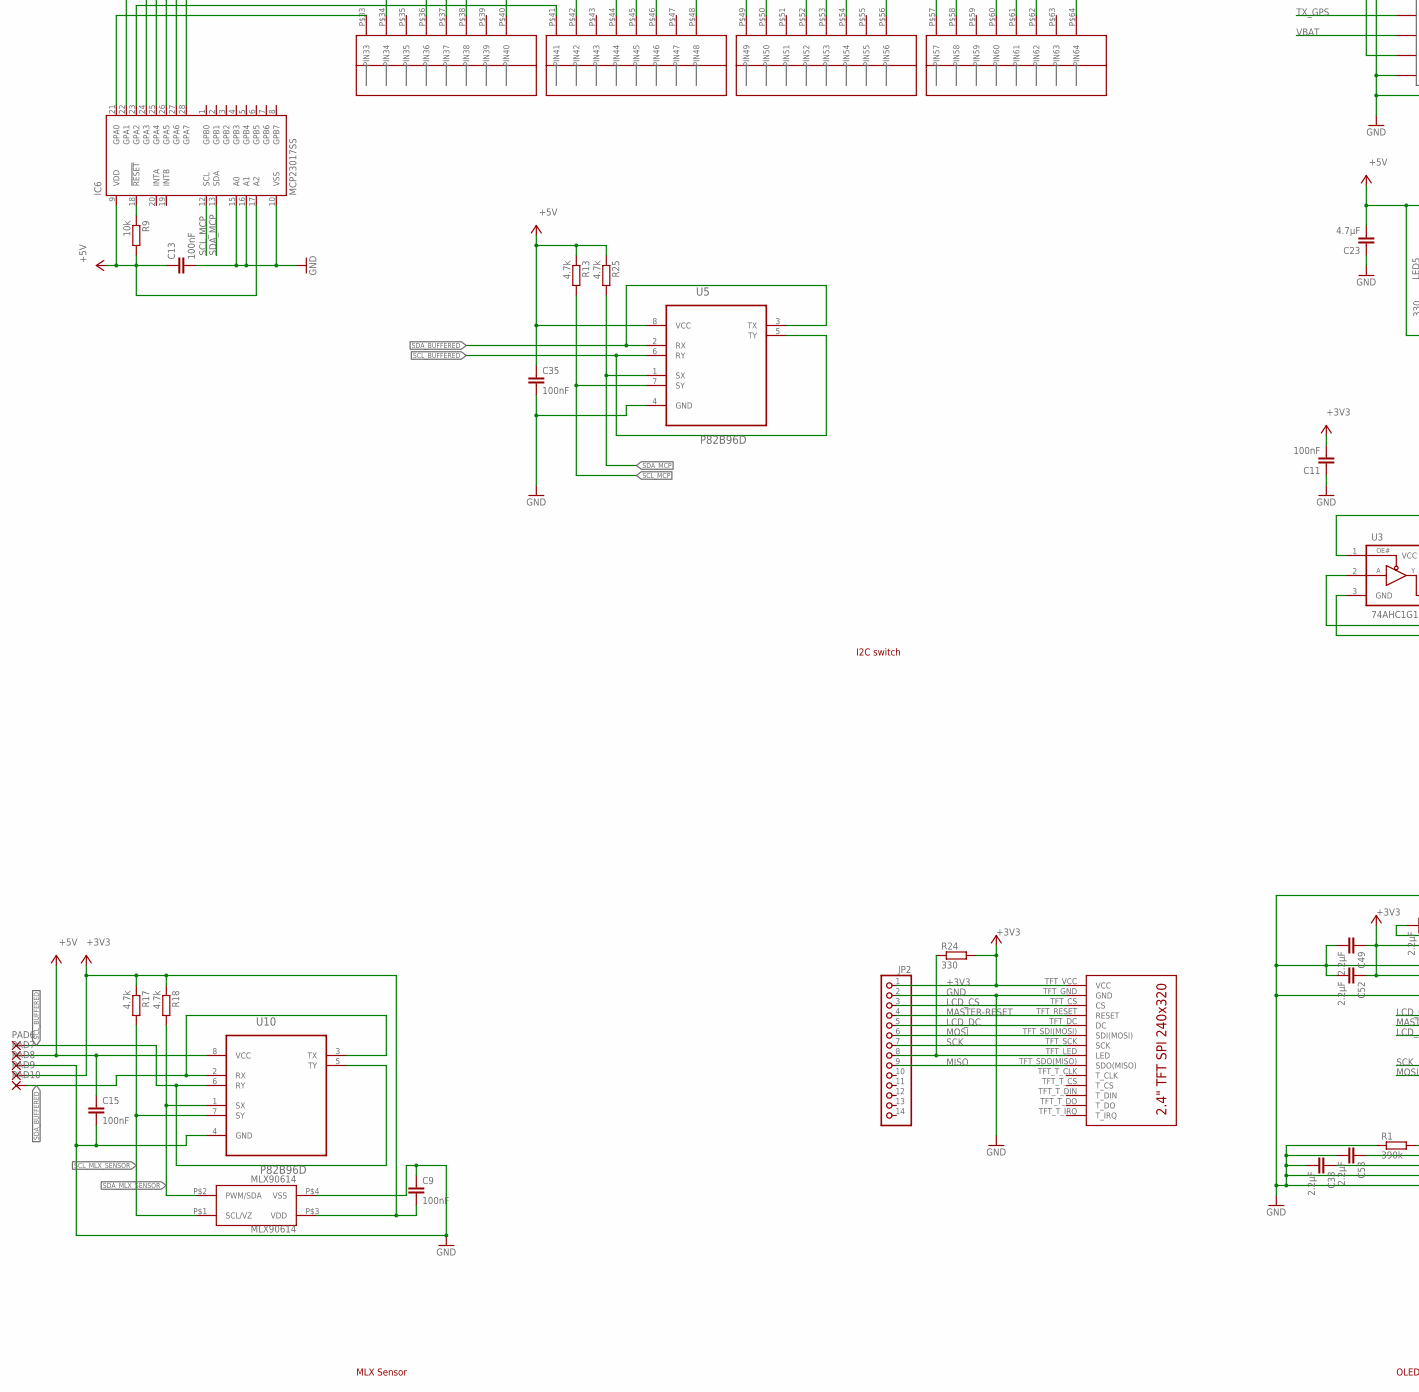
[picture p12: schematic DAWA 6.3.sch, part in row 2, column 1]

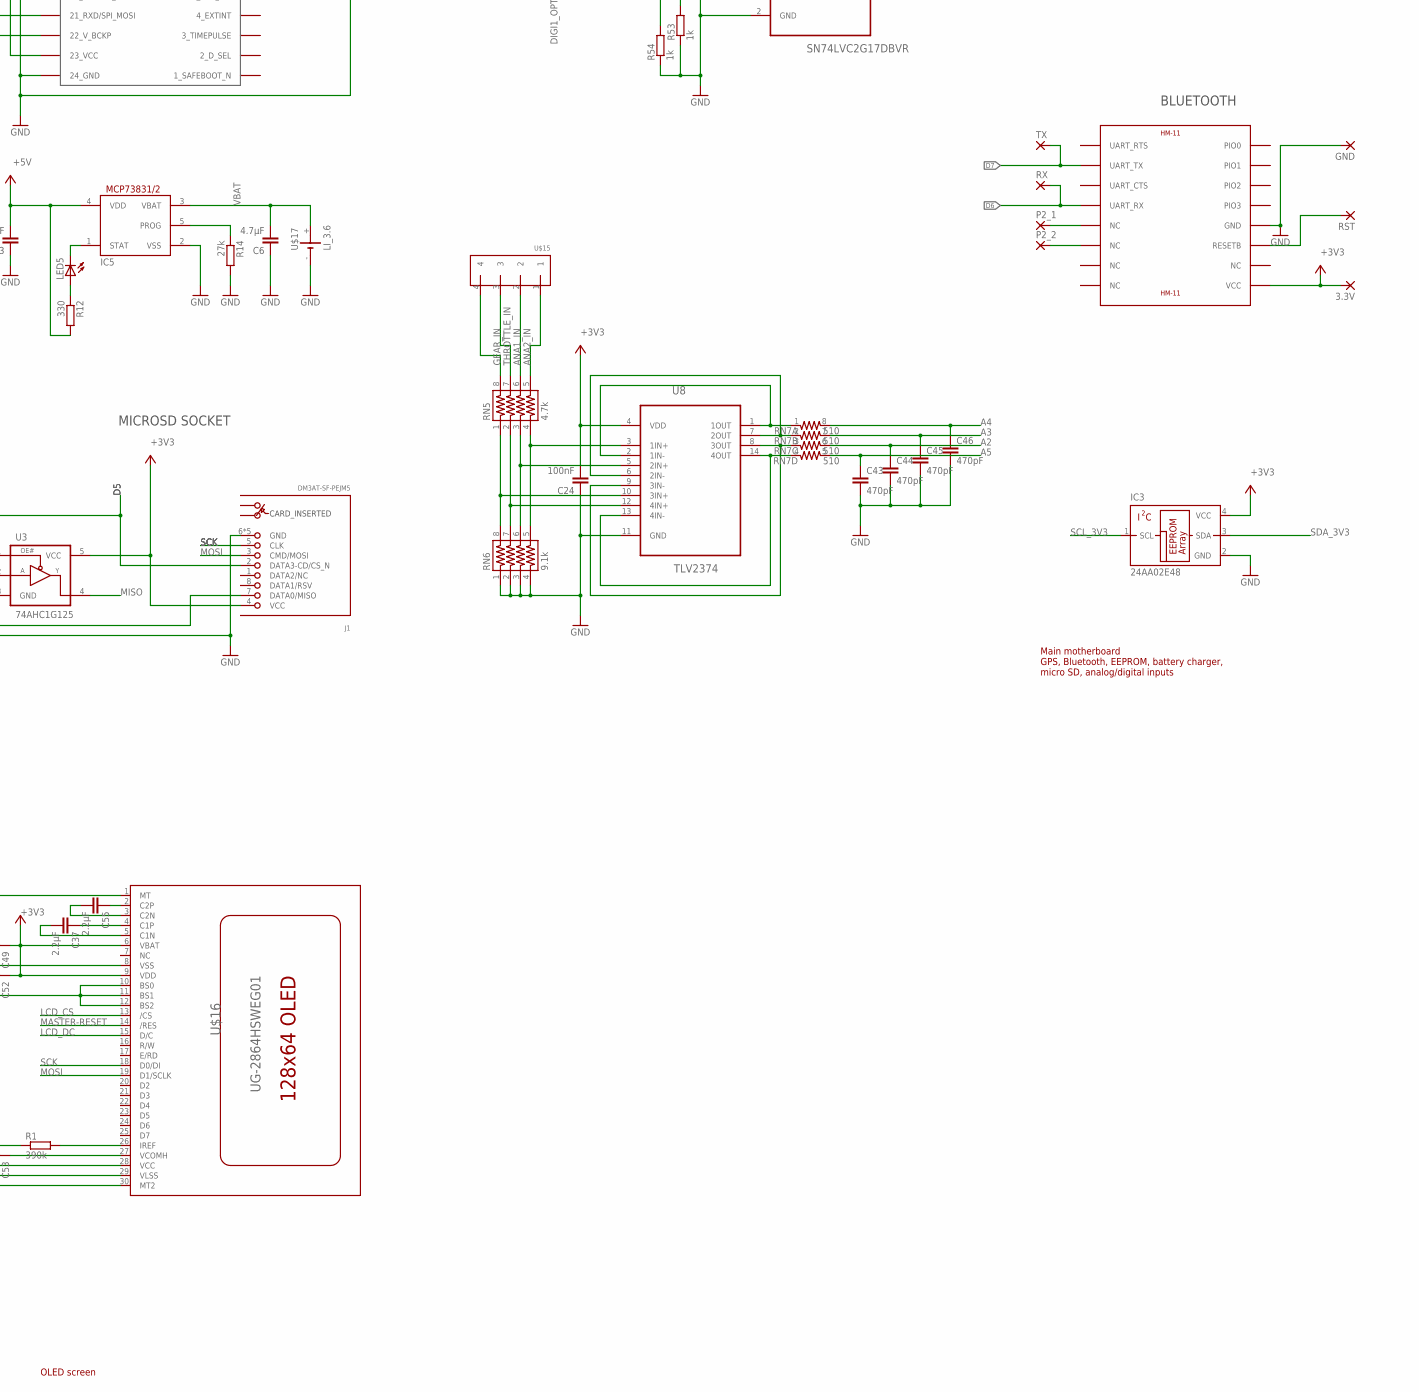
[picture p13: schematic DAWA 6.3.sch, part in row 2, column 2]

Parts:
3.3V: WIREPADSMD1,27-254; SMD1,27-2,54
+: WIREPAD4,16O1,6; 4,16O1,6
-: WIREPAD4,16O1,6; 4,16O1,6
C1, C2, C5, C7, C9, C11, C12, C13, C15, C19, C20, C24, C30, C35, C40, C47, C48, C51, C56, C57, C58: 100nF; C0603
C3, C4: 22pF; C0603
C6, C8, C23: 4.7µF; C0603
C10: 47pF; C0603
C26: 10µF; C0805
C27, C29, C41: 10µF; SMC_B
C31, C42: 10nF; C0603
C33, C37, C49, C52, C53, C55: 2.2µF; C0603
C43, C44, C45, C46: 470pF; C0603
CN2: USB; USB-MINIB-DAWA
D2, D5: MBR120; SOD-123FL
D3: CD1206-S01575; MINIMELF
F1: MF-MSMF050-2 500mA; L1812
GND: WIREPADSMD1,27-254; SMD1,27-2,54
IC1, IC6: MCP23017SS; SSOP28
IC2: LM2734Y; SOT23-6
IC3: 24AA02E48; SOT23-5L
IC4: NCP1117ST33T3G-3V3; SOT223
IC5: MCP73831/OT; SOT23-5L
IC7: LMV321M5; SOT23-5
J1: DM3AT-SF-PEJM5
JP2: PINHD-1X14-CB; 1X14-CB
JTAG: PINHEAD_PINHD-2X5PASSO127; PINHEAD_2X05_127
L1, L6: MH2029-300Y; 0805
L2: 27nH; L0603
L4: 10u SRR0604-100ML; SRR0604
LED1, LED2, LED3, LED4, LED5: LEDCHIPLED_1206; CHIPLED_1206
MLX90614: MLX90614; TO-39
P2_1, P2_2: WIREPADSMD1,27-254; SMD1,27-2,54
PAD6, PAD7, PAD8, PAD9, PAD10: WIREPAD1,6/0,9; 1,6/0,9
PC1, PC2: 47µF; PANASONIC_D
R1: 390k; R0603
R2, R3, R4, R5, R8, R9: 10k; R0603
R6, R7: 100k; R0603
R10: 52k3; R0603
R11: 10; R0603
R12, R24: 330; R0603
R13, R17, R18, R21, R22, R25, R49, R50: 4.7k; R0603
R14: 27k; R0603
R15, R16, R53, R54: 1k; R0603
R51, R52: 1.8k; R0603
RJ45_MAIN_BOARD: RJ45
RN1: 100; 742-8NS
RN2, RN7: 510; 742-8NS
RN3, RN4: 10k; 742-8NS
RN5: 4.7k; 742-8NS
RN6: 9.1k; 742-8NS
RST: WIREPADSMD1,27-254; SMD1,27-2,54
RX: WIREPADSMD1,27-254; SMD1,27-2,54
T1: FDN340P; SOT-23
TX: WIREPADSMD1,27-254; SMD1,27-2,54
U1: ATSAMD21G-A; TQFP-48
U2: PRTR5V0U2X; SOT-143B
U3: 74AHC1G125; SOT23-5
U5, U9, U10: P82B96D; SOIC127P600X175-8N
U8: TLV2374; SOP65P640X120-14N
U12, U13: SN74LVC2G17DBVR; SOT95P280X145-6N
U14: CD40106BPW; SOP65P640X120-14N
U$1: OSCILLATOR_32KHZ; OSCILLATOR_SMD
U$2: HM-11
U$3: NEO-M8
U$4: TFT_2.4
U$5, U$6, U$7, U$8: SKPMAPE10
U$9, U$15: 4_PIN_JST-XH-SMD
U$16: UG-2864HSWEG01; 1X30-0.7MM
U$17: LI_3.6
U$18: RJ45X8
X1: SMACONNECTOR_EDGE; SMA_EDGELAUNCH

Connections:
+3V3: 3.3V.1, C1.1, C5.1, C8.2, C9.2, C11.2, C24.2, C29.+, C40.1, C47.1, C48.1, C49.1, C52.1, IC1.9 (VDD), IC3.4 (VCC), IC4.2 (OUT), IC4.4 (OUT), IC7.3 (-IN), J1.4 (VCC), JP2.1, JTAG.1, L1.1, MLX90614.P$3 (VDD), PAD9.1, R2.2, R8.2, R17.1, R18.1, R21.1, R22.1, R24.2, RJ45_MAIN_BOARD.P$10 (PIN4), RN1.5 (2), RN1.6 (2), RN1.7 (2), RN1.8 (2), RN3.5 (2), RN3.6 (2), RN3.7 (2), RN3.8 (2), U1.17 (VDDIO), U1.36 (VDDIO), U1.44 (VDDIN), U3.5 (VCC), U8.4 (VDD), U12.5 (VCC), U13.5 (VCC), U14.14 (VDD), U$2.VCC, U$3.23 (23_VCC), U$4.TFT_VCC (VCC), U$16.6 (VBAT), U$16.9 (VDD), U$18.P$4 (PIN4), U$18.P$12 (PIN12), U$18.P$20 (PIN20), U$18.P$28 (PIN28), U$18.P$36 (PIN36), U$18.P$44 (PIN44), U$18.P$52 (PIN52), U$18.P$60 (PIN60)
+5V: C13.1, C15.1, C19.1, C23.2, C30.1, C35.1, D3.A, IC4.3 (IN), IC5.4 (VDD), IC6.9 (VDD), IC6.17 (A2), IC7.5 (V+), L4.P$2 (2), PAD7.1, PC2.+, R9.2, R10.2, R12.2, R13.1, R15.1, R16.1, R25.1, RJ45_MAIN_BOARD.P$5 (PIN6), T1.2 (S), U5.8 (VCC), U9.8 (VCC), U10.8 (VCC), U$18.P$6 (PIN6), U$18.P$14 (PIN14), U$18.P$22 (PIN22), U$18.P$30 (PIN30), U$18.P$38 (PIN38), U$18.P$46 (PIN46), U$18.P$54 (PIN54), U$18.P$62 (PIN62)
A2: C44.1, RN7.6 (2), U1.8 (A2_PB09(AIN3/SER4:1/TC4:1))
A3: C45.1, RN7.7 (2), U1.9 (A3_PA04(AIN4/REFB/SER0:0/TC0:0))
A4: C46.1, RN7.8 (2), U1.10 (A4_PA05(AIN5/SER0:1/TC0:1))
A5: C43.1, RN7.5 (2), U1.47 (A5_PB02(AIN10/SER5:0))
ALIM+: +.1, L6.2
ANA1_IN: RN5.6, U$15.2
ANA2_IN: RN5.5, U$15.1
BOOST: C42.1, D3.C, IC2.1 (BOOST)
BRAKE_IN: R51.1, U$9.2
CMP: C7.1, IC7.1 (+IN), R6.1, R7.2
D3: RN2.7 (2), U1.14 (PA09(I2C/AIN17/SER0:1+)_D3)
D4: U1.13 (PA08(I2C/AIN16/SER0:0+)_D4)
D5: J1.2 (DATA3-CD/CS_N), U1.24 (PA15(XOUT/SER2:3+)_D5), U3.1 (OE#)
D6: RX.1, U1.29 (PA20(SER5:2+)_D6), U$2.UART_RX
D7: TX.1, U1.30 (PA21(SER5:3+)_D7), U$2.UART_TX
D10: RN2.5 (2), U1.27 (PA18(SER1:2+)_D10)
D12: RN2.6 (2), U1.28 (PA19(SER1:3+)_D12)
DIGI1_OPT: RN2.8 (2), U1.25 (PA16(I2C/SER1:0+)_D11)
DIGI1_OPT_IN: R52.1, U$9.1
EN: IC2.4 (EN), R3.2
FB: IC2.3 (FB), R5.2, R10.1
GATE_CMD: IC7.4 (OUT), T1.3 (G)
GEAR_IN: RN5.8, U$15.4
GND: -.1, C1.2, C2.2, C3.2, C4.2, C5.2, C6.1, C7.2, C8.1, C9.1, C10.1, C11.1, C12.2, C13.2, C15.2, C19.2, C20.2, C23.1, C24.1, C26.2, C27.-, C29.-, C30.2, C31.2, C33.2, C35.2, C40.2, C41.-, C43.2, C44.2, C45.2, C46.2, C47.2, C48.2, C49.2, C51.2, C52.2, C53.2, C56.2, C57.2, C58.2, CN2.GND, CN2.GND1 (GND), CN2.GND2 (GND), D2.A, GND.1, IC1.10 (VSS), IC1.15 (A0), IC1.16 (A1), IC1.17 (A2), IC2.2 (GND), IC3.2 (GND), IC4.1 (GND/ADJ), IC5.2 (VSS), IC6.10 (VSS), IC6.15 (A0), IC6.16 (A1), IC7.2 (V-), J1.6 (GND), J1.MOUNT0 (GND), J1.MOUNT1 (GND), J1.MOUNT2 (GND), J1.MOUNT3 (GND), JP2.2, JTAG.3, JTAG.5, JTAG.9, MLX90614.P$4 (VSS), PAD8.1, PC1.-, PC2.-, R1.1, R4.1, R5.1, R6.2, R14.2, R53.1, R54.1, RJ45_MAIN_BOARD.P$7 (PIN5), RN6.1, RN6.2, RN6.3, RN6.4, U1.5 (GNDANA), U1.18 (GND), U1.35 (GND), U1.42 (GND), U2.1 (GND), U3.3 (GND), U5.4 (GND), U8.11 (GND), U9.4 (GND), U10.4 (GND), U12.2 (GND), U13.2 (GND), U14.7 (VSS), U$2.GND, U$3.7 (7_VDD_USB), U$3.10 (10_GND), U$3.12 (12_GND), U$3.13 (13_GND), U$3.24 (24_GND), U$4.TFT_GND (GND), U$5.P$1, U$6.P$1, U$7.P$1, U$8.P$1, U$16.1 (MT), U$16.8 (VSS), U$16.10 (BS0), U$16.11 (BS1), U$16.12 (BS2), U$16.29 (VLSS), U$16.30 (MT2), U$17.-, U$18.P$5 (PIN5), U$18.P$13 (PIN13), U$18.P$21 (PIN21), U$18.P$29 (PIN29), U$18.P$37 (PIN37), U$18.P$45 (PIN45), U$18.P$53 (PIN53), U$18.P$61 (PIN61), U$18.P$67 (SHD), U$18.P$68 (SHD), U$18.P$69 (SHD), U$18.P$70 (SHD), U$18.P$71 (SHD), U$18.P$72 (SHD), X1.GND@1 (GND4), X1.GND@2 (GND3), X1.GND@3 (GND2), X1.GND@4 (GND1)
LCD_CS: JP2.3, U1.26 (PA17(I2C/SER1:1+)_D13), U$4.TFT_CS (CS), U$16.13 (/CS)
LCD_DC: JP2.5, U1.12 (D9_PA07(AIN7/SER0:3/TC1:1)), U$4.TFT_DC (DC), U$16.15 (D/C)
MASTER-RESET: C20.1, JP2.4, JTAG.10, R2.1, U1.40 (!RESET!), U$4.TFT_RESET (RESET), U$16.14 (/RES)
MCP1_INT: IC1.20 (INTA), U1.11 (D8_PA06(AIN6/SER0:2/TC1:0))
MISO: JP2.9, U1.21 (PA12(I2C/SER2:0+)_MISO), U3.4 (Y), U$4.TFT_SDO(MISO) (SDO(MISO))
MOSI: J1.3 (CMD/MOSI), JP2.6, U1.19 (PB10(SER4:2+)_MOSI), U$4.TFT_SDI(MOSI) (SDI(MOSI)), U$16.19 (D1/SCLK)
unnamed: C2.1, U1.43 (VDDCORE)
unnamed: C3.1, U1.1 (PA00(XIN32/SER1:0/TC2:0)), U$1.2
unnamed: C4.1, U1.2 (PA01(XOUT32/SER1:1/TC2:1)), U$1.1
unnamed: RN5.4, RN6.5, U8.3 (1IN+)
unnamed: IC1.1 (GPB0), LED4.C
unnamed: IC5.1 (STAT), LED5.C
unnamed: IC1.2 (GPB1), LED3.C
unnamed: LED5.A, R12.1
unnamed: D5.A, L6.1
unnamed: C10.2, L2.1, R11.2
unnamed: IC5.5 (PROG), R14.1
unnamed: J1.7 (DATA0/MISO), U3.2 (A)
unnamed: P2_1.1, U$2.NC@5 (NC)
unnamed: RST.1, U$2.RESETB
unnamed: P2_2.1, U$2.NC@6 (NC)
unnamed: R11.1, U$3.9 (9_VCC_RF)
unnamed: L2.2, U$3.11 (11_RF_IN), X1.P (ANT)
unnamed: RN5.3, RN6.6, U8.5 (2IN+)
unnamed: IC1.3 (GPB2), LED2.C
unnamed: IC1.4 (GPB3), LED1.C
unnamed: RN7.1, U8.1 (1OUT), U8.2 (1IN-)
unnamed: RN7.2 (1), U8.6 (2IN-), U8.7 (2OUT)
unnamed: RN7.3 (1), U8.8 (3OUT), U8.9 (3IN-)
unnamed: RN7.4 (1), U8.13 (4IN-), U8.14 (4OUT)
unnamed: RN5.2, RN6.7, U8.12 (4IN+)
unnamed: LED4.A, RN1.4 (1)
unnamed: LED3.A, RN1.3 (1)
unnamed: RN5.1, RN6.8, U8.10 (3IN+)
unnamed: LED2.A, RN1.2 (1)
unnamed: LED1.A, RN1.1
unnamed: IC1.18 (!RESET), R8.1
unnamed: IC6.28 (GPA7), U$18.P$25 (PIN25)
unnamed: RN2.3 (1), U12.6 (1Y)
unnamed: RN3.4 (1), RN4.5 (2), U$5.P$2
unnamed: RN3.3 (1), RN4.6 (2), U$6.P$2
unnamed: IC6.26 (GPA5), U$18.P$17 (PIN17)
unnamed: IC6.24 (GPA3), U$18.P$9 (PIN9)
unnamed: R50.2, U12.1 (1A)
unnamed: R49.2, U12.3 (2A)
unnamed: R51.2, R53.2, U13.3 (2A)
unnamed: R52.2, R54.2, U13.1 (1A)
unnamed: RN2.1, U13.6 (1Y)
unnamed: RN2.2 (1), U13.4 (2Y)
unnamed: JP2.8, R24.1, U$4.TFT_LED (LED)
unnamed: RN2.4 (1), U12.4 (2Y)
unnamed: RN3.1, RN4.8 (2), U$8.P$2
unnamed: RN3.2 (1), RN4.7 (2), U$7.P$2
unnamed: IC6.22 (GPA1), U$18.P$1 (PIN1)
unnamed: IC6.21 (GPA0), U$18.P$33 (PIN33)
unnamed: IC6.23 (GPA2), U$18.P$41 (PIN41)
unnamed: IC6.25 (GPA4), U$18.P$49 (PIN49)
unnamed: IC6.27 (GPA6), U$18.P$57 (PIN57)
unnamed: IC6.18 (!RESET), R9.1
unnamed: IC1.21 (GPA0), U14.2 (G=~A)
unnamed: IC1.22 (GPA1), U14.4 (H=~B)
unnamed: R1.2, U$16.26 (IREF)
unnamed: C55.1, U$16.2 (C2P)
unnamed: C55.2, U$16.3 (C2N)
unnamed: C37.1, U$16.4 (C1P)
unnamed: C37.2, U$16.5 (C1N)
unnamed: C33.1, U$16.28 (VCC)
unnamed: C53.1, U$16.27 (VCOMH)
unnamed: IC1.23 (GPA2), U14.6 (I=~C)
unnamed: IC1.24 (GPA3), U14.8 (J=~D)
unnamed: C51.1, RN4.4 (1), U14.9 (D)
unnamed: C56.1, RN4.3 (1), U14.5 (C)
unnamed: C57.1, RN4.2 (1), U14.3 (B)
unnamed: C58.1, RN4.1, U14.1 (A)
RPM_IN: R49.1, U$9.4
RX_GPS: U1.16 (PA11(AIN19/SER0:3+)_D0/RX), U$3.20 (20_TXD/SPI_MISO)
SCK: J1.5 (CLK), JP2.7, U1.20 (PB11(SER4:3+)_SCK), U$4.TFT_SCK (SCK), U$16.18 (D0/DI)
SCL_3V3: IC1.12 (SCL), IC3.1 (SCL), R22.2, U1.32 (PA23(I2C/SER3:0+)_SCL), U9.7 (SY)
SCL_BUFFERED: PAD6.1, R16.2, RJ45_MAIN_BOARD.P$4 (PIN8), U5.5 (TY), U5.6 (RY), U9.5 (TY), U9.6 (RY), U10.5 (TY), U10.6 (RY), U$18.P$8 (PIN8), U$18.P$16 (PIN16), U$18.P$24 (PIN24), U$18.P$32 (PIN32), U$18.P$40 (PIN40), U$18.P$48 (PIN48), U$18.P$56 (PIN56), U$18.P$64 (PIN64)
SCL_MCP: IC6.12 (SCL), R13.2, U5.7 (SY)
SCL_MLX_SENSOR: MLX90614.P$1 (SCL/VZ), R17.2, U10.7 (SY)
SDA_3V3: IC1.13 (SDA), IC3.3 (SDA), R21.2, U1.31 (PA22(I2C/SER3:0+)_SDA), U9.1 (SX)
SDA_BUFFERED: PAD10.1, R15.2, RJ45_MAIN_BOARD.P$3 (PIN2), U5.2 (RX), U5.3 (TX), U9.2 (RX), U9.3 (TX), U10.2 (RX), U10.3 (TX), U$18.P$2 (PIN2), U$18.P$10 (PIN10), U$18.P$18 (PIN18), U$18.P$26 (PIN26), U$18.P$34 (PIN34), U$18.P$42 (PIN42), U$18.P$50 (PIN50), U$18.P$58 (PIN58)
SDA_MCP: IC6.13 (SDA), R25.2, U5.1 (SX)
SDA_MLX_SENSOR: MLX90614.P$2 (PWM/SDA), R18.2, U10.1 (SX)
SQR_OPT_IN: R50.1, U$9.3
SW: C42.2, D2.C, IC2.6 (SW), L4.P$1 (1)
SWCLK: JTAG.4, U1.45 (PA30(SWCLK/SER1:2+))
SWDIO: JTAG.2, U1.46 (PA31(SWDIO/SER1:3+))
THROTTLE_IN: RN5.7, U$15.3
TX_GPS: U1.15 (PA10(AIN18/SER0:2+)_D1/TX), U$3.21 (21_RXD/SPI_MOSI)
USBVCC: C27.+, F1.1, R4.2, T1.1 (D)
USB_D+: CN2.D+, U1.34 (PA25(SER3:3+)), U2.2 (IO1)
USB_D-: CN2.D-, U1.33 (PA24(SER3:2+)), U2.3 (IO2)
VBAT: C6.2, IC5.3 (VBAT), U$3.22 (22_V_BCKP), U$17.+
VDDANA: C12.1, C26.1, L1.2, U1.6 (VDDANA)
VIN: C41.+, D5.C, IC2.5 (VIN), PC1.+, R3.1, R7.1
VUSB: C31.1, CN2.VBUS, F1.2, U2.4 (VCC)

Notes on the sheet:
GPS
MICROSD SOCKET
BLUETOOTH
MLX Sensor
OLED screen
I2C switch
Main motherboard Power, leds, buttons, RJ45 I2C connector
Main motherboard GPS, Bluetooth, EEPROM, battery charger, micro SD, analog/digital inputs

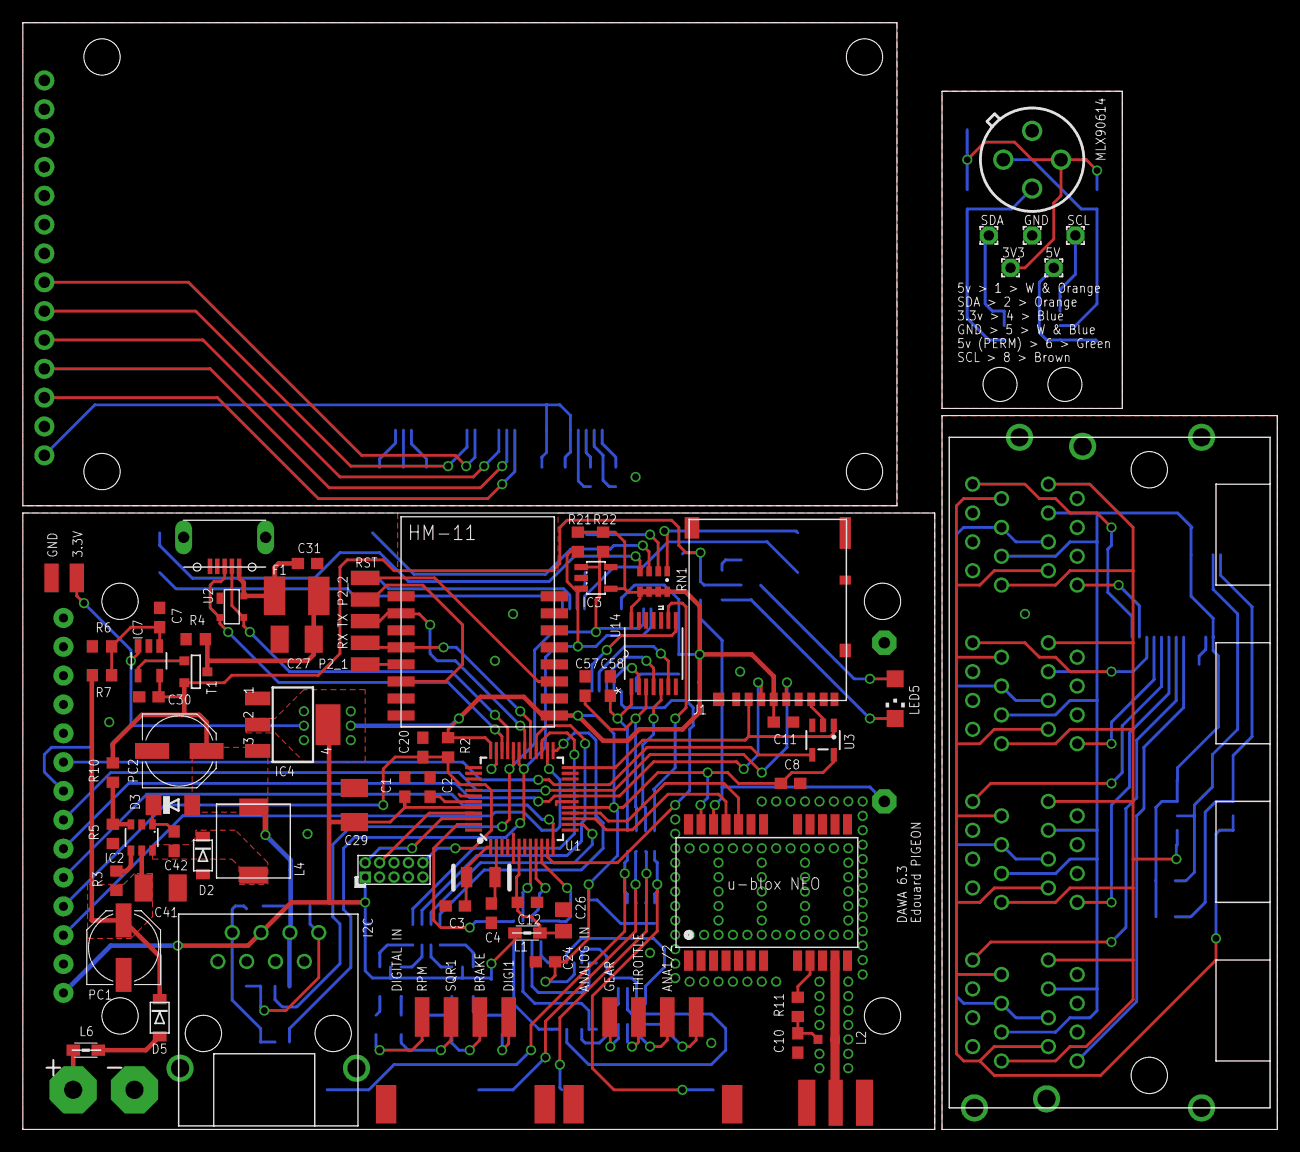
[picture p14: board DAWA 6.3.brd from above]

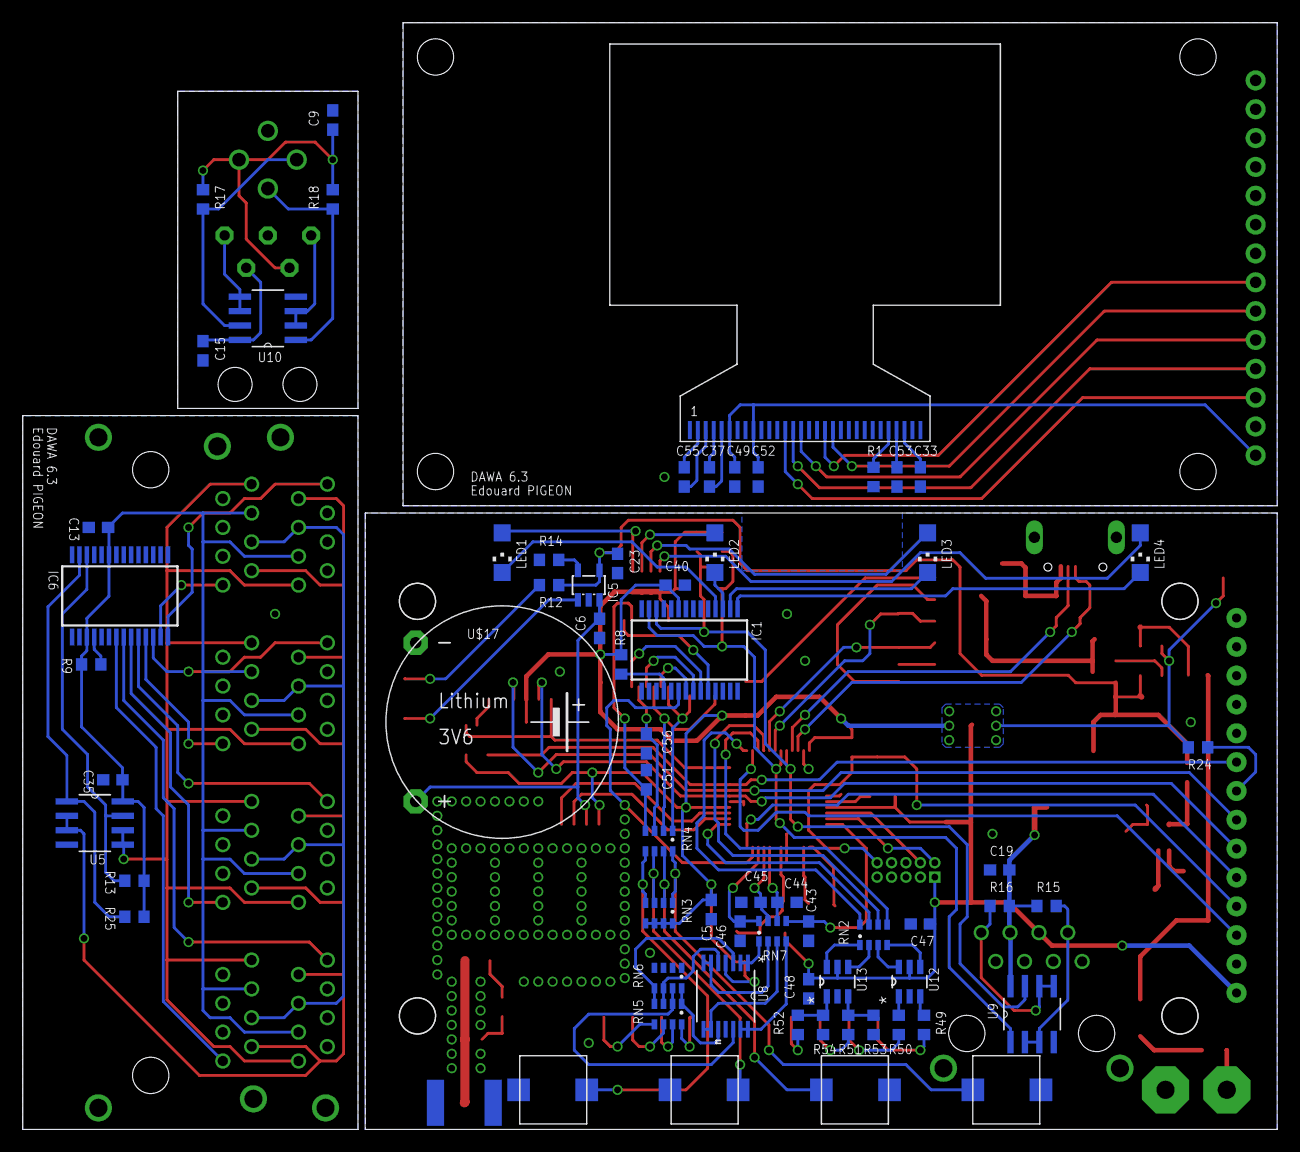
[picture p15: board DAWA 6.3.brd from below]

Board: 2 copper layers, 110.5 x 97.5 mm, 145 parts (67 on the bottom side), 123 nets.

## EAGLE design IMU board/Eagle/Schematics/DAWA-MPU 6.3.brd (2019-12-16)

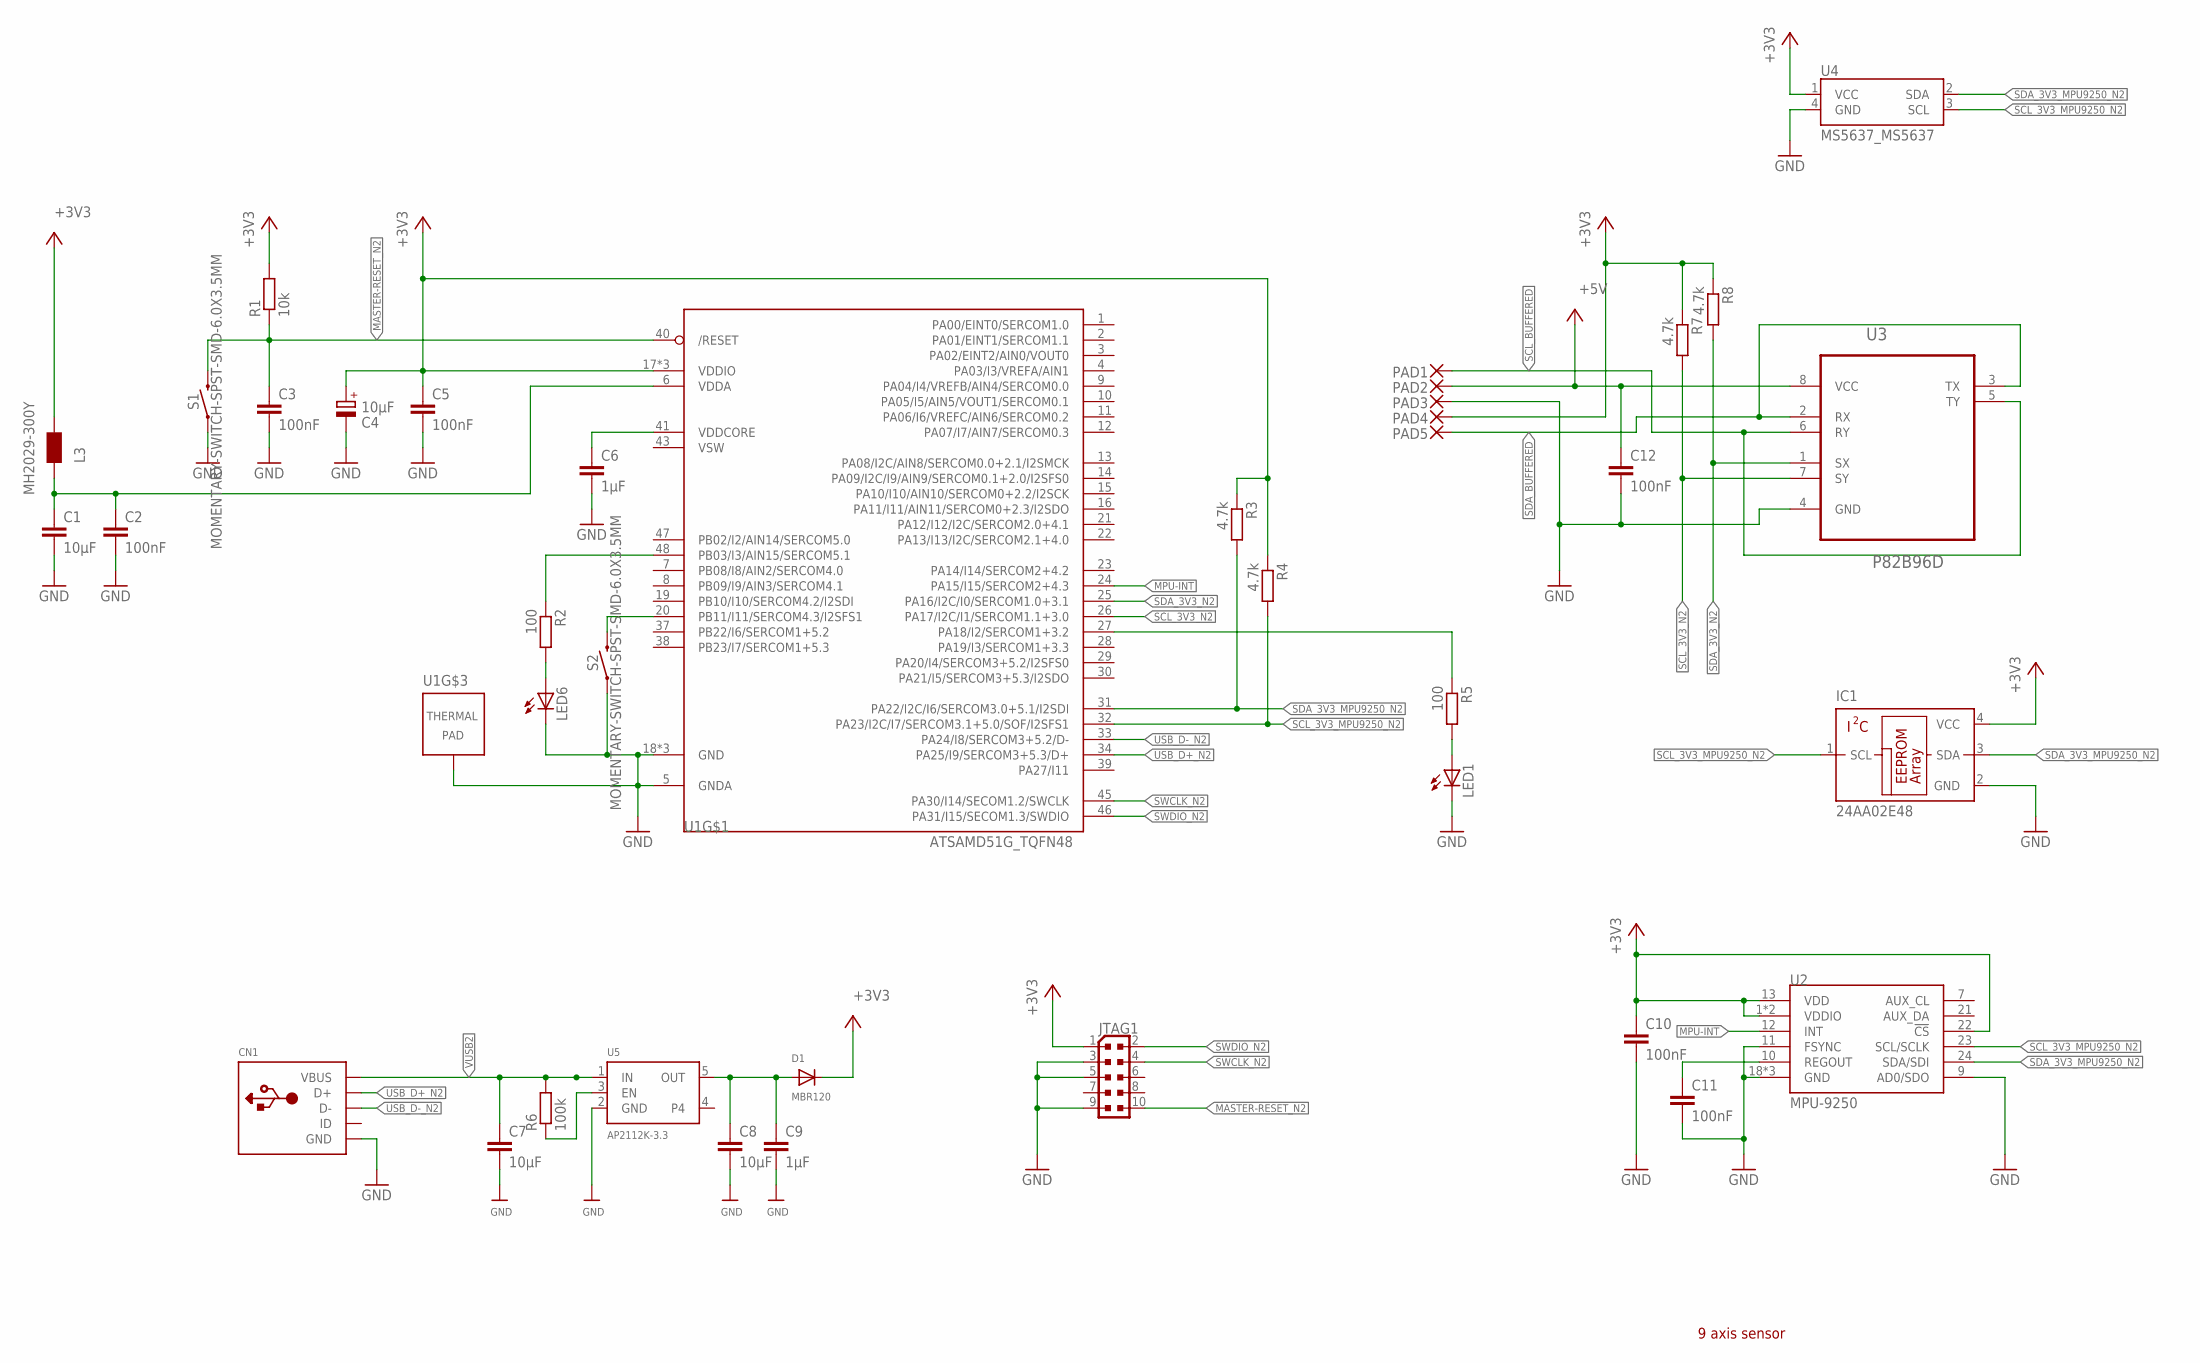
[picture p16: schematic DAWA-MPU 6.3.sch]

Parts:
C1: 10µF; C0805
C2, C3, C5, C10, C11, C12: 100nF; C0603
C4: 10µF; SMC_B
C6, C9: 1µF; C0603
C7, C8: 10µF; C0603
CN1: USB; USB-MINIB-DAWA
D1: MBR120; SOD-123FL
IC1: 24AA02E48; SOT23-5L
JTAG1: PINHEAD_PINHD-2X5PASSO127; PINHEAD_2X05_127
L3: MH2029-300Y; 0805
LED1, LED6: LEDCHIPLED_1206; CHIPLED_1206
PAD1, PAD2, PAD3, PAD4, PAD5: WIREPAD1,6/0,9; 1,6/0,9
R1: 10k; R0603
R2, R5: 100; R0603
R3, R4, R7, R8: 4.7k; R0603
R6: 100k; R0603
S1, S2: MOMENTARY-SWITCH-SPST-SMD-6.0X3.5MM; TACTILE_SWITCH_SMD_6.0X3.5MM
U1: ATSAMD51G_TQFN48; TQFN48_7MM
U2: MPU-9250; QFN24_PAD
U3: P82B96D; SOIC127P600X175-8N
U4: MS5637_MS5637
U5: AP2112K-3.3; SOT23-5

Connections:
+3V1: R2.1, U1.48 (PB03/I3/AIN15/SERCOM5.1)
+3V2: R5.1, U1.27 (PA18/I2/SERCOM1+3.2)
+3V3: C4.+, C5.1, C10.1, D1.C, IC1.4 (VCC), JTAG1.1, L3.1, PAD4.1, R1.2, R3.1, R4.1, R7.1, R8.1, U1.17 (VDDIO), U1.36 (VDDIO), U1.44 (VDDIO), U2.1 (VDDIO), U2.8 (VDDIO), U2.13 (VDD), U2.22 (!CS), U4.1 (VCC)
+5V: C12.1, PAD2.1, U3.8 (VCC)
GND: C1.2, C2.2, C3.2, C4.-, C5.2, C6.2, C7.2, C8.2, C9.2, C10.2, C11.2, C12.2, CN1.GND, CN1.GND1 (GND), CN1.GND2 (GND), IC1.2 (GND), JTAG1.3, JTAG1.5, JTAG1.9, LED1.C, LED6.C, PAD3.1, S1.1, S2.1, U1.5 (GNDA), U1.18 (GND), U1.35 (GND), U1.42 (GND), U1.THERMAL (TP), U2.9 (AD0/SDO), U2.11 (FSYNC), U2.18 (GND), U2.20 (GND), U2.CENTER (GND), U3.4 (GND), U4.4 (GND), U5.2 (GND)
MASTER-RESET_N2: C3.1, JTAG1.10, R1.1, S1.2, U1.40 (/RESET)
MPU-INT: U1.24 (PA15/I15/SERCOM2+4.3), U2.12 (INT)
unnamed: LED1.A, R5.2
unnamed: C6.1, U1.41 (VDDCORE)
unnamed: S2.2, U1.20 (PB11/I11/SERCOM4.3/I2SFS1)
unnamed: LED6.A, R2.2
unnamed: R6.1, U5.3 (EN)
OUT: C8.1, C9.1, D1.A, U5.5 (OUT)
REGOUT: C11.1, U2.10 (REGOUT)
SCL_3V3_MPU9250_N2: IC1.1 (SCL), R4.2, U1.32 (PA23/I2C/I7/SERCOM3.1+5.0/SOF/I2SFS1), U2.23 (SCL/SCLK), U4.3 (SCL)
SCL_3V3_N2: R7.2, U1.26 (PA17/I2C/I1/SERCOM1.1+3.0), U3.7 (SY)
SCL_BUFFERED: PAD1.1, U3.5 (TY), U3.6 (RY)
SDA_3V3_MPU9250_N2: IC1.3 (SDA), R3.2, U1.31 (PA22/I2C/I6/SERCOM3.0+5.1/I2SDI), U2.24 (SDA/SDI), U4.2 (SDA)
SDA_3V3_N2: R8.2, U1.25 (PA16/I2C/I0/SERCOM1.0+3.1), U3.1 (SX)
SDA_BUFFERED: PAD5.1, U3.2 (RX), U3.3 (TX)
SWCLK_N2: JTAG1.4, U1.45 (PA30/I14/SECOM1.2/SWCLK)
SWDIO_N2: JTAG1.2, U1.46 (PA31/I15/SECOM1.3/SWDIO)
USB_D+_N2: CN1.D+, U1.34 (PA25/I9/SERCOM3+5.3/D+)
USB_D-_N2: CN1.D-, U1.33 (PA24/I8/SERCOM3+5.2/D-)
VDDANA1: C1.1, C2.1, L3.2, U1.6 (VDDA)
VSW: U1.43 (VSW)
VUSB2: C7.1, CN1.VBUS, R6.2, U5.1 (IN)

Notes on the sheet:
9 axis sensor

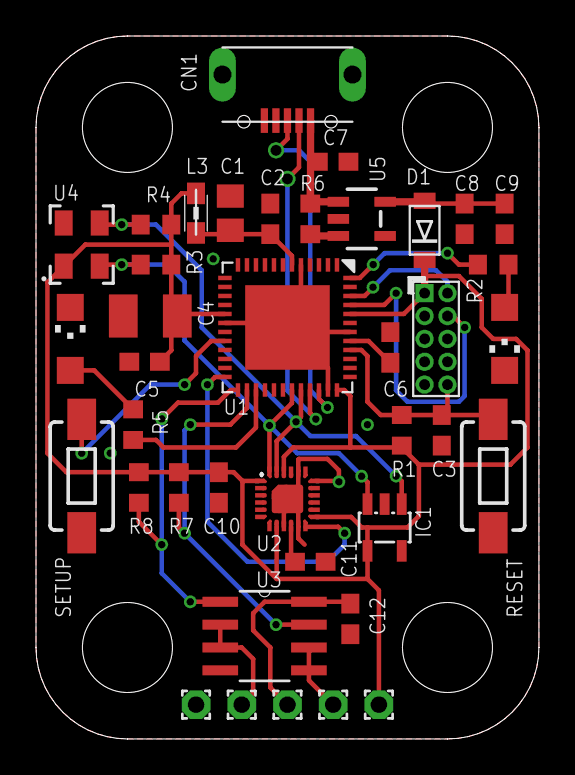
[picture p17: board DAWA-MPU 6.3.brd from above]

Board: 2 copper layers, 27.9 x 39.1 mm, 39 parts (0 on the bottom side), 26 nets.

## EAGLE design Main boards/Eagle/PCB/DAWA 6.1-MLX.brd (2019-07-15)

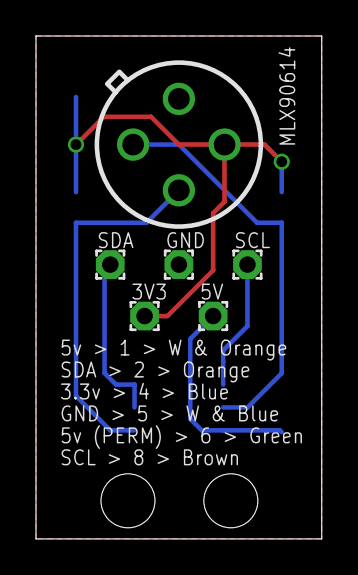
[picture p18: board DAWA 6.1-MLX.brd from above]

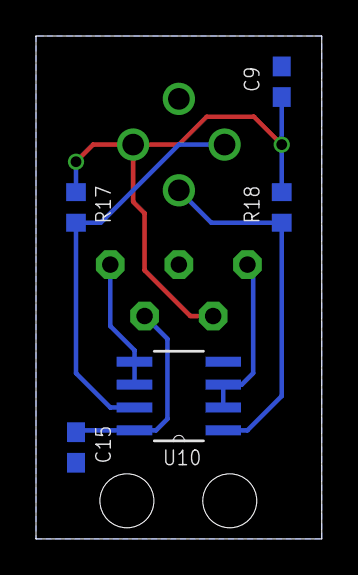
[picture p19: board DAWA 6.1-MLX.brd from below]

Board: 2 copper layers, 15.9 x 27.9 mm, 11 parts (5 on the bottom side), 7 nets.

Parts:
C9, C15: 100nF; C0603
MLX90614: MLX90614; TO-39
PAD6, PAD7, PAD8, PAD9, PAD10: 1,6/0,9
R17, R18: 4.7k; R0603
U10: P82B96D; SOIC127P600X175-8N

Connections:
+3V3: C9.2, MLX90614.P$3, PAD9.1, R17.1, R18.1
+5V: C15.1, PAD7.1, U10.8
GND: C9.1, C15.2, MLX90614.P$4, PAD8.1, U10.4
SCL_BUFFERED: PAD6.1, U10.5, U10.6
SCL_MLX_SENSOR: MLX90614.P$1, R17.2, U10.7
SDA_BUFFERED: PAD10.1, U10.2, U10.3
SDA_MLX_SENSOR: MLX90614.P$2, R18.2, U10.1

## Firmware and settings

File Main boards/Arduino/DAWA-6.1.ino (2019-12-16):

/**************************************************************
  DAWA 6.1 (Arduino M0 - Onboard SAMD21G)
  Bootloader have to be burned on new chip with for example Atmel ICE
  Triumph motorbikes laptimer/datalogger
  Edouard PIGEON - 2019
**************************************************************/

/**************************************************************
  TODO
  Terminer/vérifier log fichiers
  Angle inclinaison
  Ajouter nom circuit au nom du fichier
  Ajouter bluetooth init test
  Select tracks > view tracks
  View last laptimes
**************************************************************/

/**************************************************************
  Enable debug output to serial
**************************************************************/
#define DEBUG // /!\ DAWA will wait serial connection to start

/**************************************************************
  Debug to serial
  Also used by NeoGPS library
**************************************************************/
#ifdef DEBUG
#define DEBUG_PORT SERIAL_PORT_USBVIRTUAL
#endif

/**************************************************************
  #################################################
  ############## Includes definition ##############
  #################################################
**************************************************************/

/**************************************************************
  SPI library
  It's included with Arduino
**************************************************************/
#include <SPI.h>

/**************************************************************
  I2C library
  It's included with Arduino
**************************************************************/
#include <Wire.h>

/**************************************************************
  EEPROM library
  It's included with Arduino

    extEEPROM.c >
  //REMOVE l.98 :
  //TWBR = ( (F_CPU / twiFreq) - 16) / 2;

  //REPLACE l.98 :
  //sercom3.disableWIRE();                         // Disable the I2C bus
  //SERCOM3->I2CM.BAUD.bit.BAUD = SystemCoreClock / ( 2 * 400000) - 1 ;   // // Set the I2C SCL frequency to 400kHz
  //sercom3.enableWIRE();                          // Restart the I2C bus
  // https://forum.arduino.cc/index.php?topic=347425.0

  extEEPROM.h >
  ADD l.63 :
  #define BUFFER_LENGTH 64 // Add var here because no more defined in wire.h (SAMD21's buffer = 64)

  EEPROM addresses used :
  0-21 BNO Calibration offsets (11x uint16_t)
  25 Ask a calibration offset
  30 ADC disabled bits (1x uint8_t)
  31-32 Throttle max value (1x int16_t)
  33-46 Gear calibration data (7x int16_t)
  50-55 MLX I2C Address (x uint8_t ... 6 max)
**************************************************************/
#include <extEEPROM.h> // Arduino External EEPROM Library v3.0 (Official Github : https://github.com/JChristensen/extEEPROM)
extEEPROM eep(kbits_2, 1, 8); // I2C Address 0x50

/**************************************************************
  Modification of the EEPROMAnything library that allows you to read and write any data structure or array to and from the external EEPROM
  https://forum.arduino.cc/index.php?topic=358648.0
**************************************************************/
#include <EEPROMAnything2.h> // Enable object read/write on EEPROM

/**************************************************************
  I/O Expander MCP23017
  https://github.com/adafruit/Adafruit-MCP23017-Arduino-Library
**************************************************************/
#include <Adafruit_MCP23017.h>

/**************************************************************
  Time library
  https://github.com/PaulStoffregen/Time
  Please rename in "TimeLib.h" var "DAYS_PER_WEEK" to "DAYS_PER_WEEK_ALT" as the same var is already used in NeoGPS library
**************************************************************/
#include <Time.h>
#include <TimeLib.h>

/**************************************************************
  Greiman/SdFat library
  https://github.com/greiman/SdFat
**************************************************************/
#include <SdFat.h>

/**************************************************************
  MLX90614 Infrared temperature sensor
  https://github.com/jfitter/MLX90614
**************************************************************/
#include <MLX90614.h>

/**************************************************************
  Modified dtostrf function defnition
  http://forum.arduino.cc/index.php?topic=368720.0
**************************************************************/
#include <dtostrf.h>

/**************************************************************
  NeoGPS library
  https://github.com/SlashDevin/NeoGPS

  NeoTime.h :
  static const uint16_t s_epoch_year    = POSIX_EPOCH_YEAR;
  static const uint8_t  s_epoch_weekday = POSIX_EPOCH_WEEKDAY;
**************************************************************/
#include <NMEAGPS.h>
HardwareSerial & GPS_PORT = Serial5;

/**************************************************************
  Bluetooth (HM11 - CC2541)
  http://jnhuamao.cn/bluetooth.asp?id=1
  If you get counterfeit HM-11, some commands won't probably work. Try flash it with original firmware :
  https://forum.arduino.cc/index.php?topic=393655.0
**************************************************************/
#include <wiring_private.h> // pinPeripheral() function
Uart BLUETOOTH_PORT (&sercom5, 7, 6, SERCOM_RX_PAD_3, UART_TX_PAD_2); //Disable SERCOM5 in <APPDATA>\local\Arduino15\packages\arduino\hardware\samd\1.6.14\variants\arduino_mzero\variant.cpp (Serial + Sercom5)

/**************************************************************
  LCD library
  SPI ASCII OLED : https://github.com/greiman/SSD1306Ascii
**************************************************************/
// SPI ASCII OLED libraries
#include <SSD1306Ascii.h> // OLED LCD based on SSD1306 chip, ASCII only no graphics
#include <SSD1306AsciiSpi.h>
#define OLED_DC 9
#define OLED_CS 13

/**************************************************************
  Menu library
  https://github.com/jonblack/arduino-menusystem
**************************************************************/
#include <MenuSystem.h>

/**************************************************************
  ##################################################
  ############## Constants definition ##############
  ##################################################
**************************************************************/

// I/O Pins
const uint8_t inDigiBrakePin = 3; // D3, digital input
const uint8_t inDigiOpt1Pin = 11; // D11, digital input
const uint8_t inAnaThrottlePin = A5; // A5, analog input
const uint8_t inAnaGearPin = A2; // A2, analog input
const uint8_t inAnaOpt1Pin = A3; // A3, analog input
const uint8_t inAnaOpt2Pin = A4; // A4, analog input
const uint8_t sdCsPin = 5; // D5, Chip Select for SDCARD on SPI bus
const uint8_t mcp1IntPin = 8; // D8, Buttons interrupt (MCP23017)
const uint8_t mcp1But1 = 0; // Button 1 on MCP23017
const uint8_t mcp1But2 = 1; // Button 2 on MCP23017
const uint8_t mcp1But3 = 2; // Button 3 on MCP23017
const uint8_t mcp1But4 = 3; // Button 4 on MCP23017
const uint8_t mcp1Led1 = 11; // Led 1 on MCP23017
const uint8_t mcp1Led2 = 10; // Led 1 on MCP23017
const uint8_t mcp1Led3 = 9; // Led 1 on MCP23017
const uint8_t mcp1Led4 = 8; // Led 1 on MCP23017

// Others ...
const char csvDelim = ';'; // CSV file delimiter
const uint8_t maxTrackDistance = 5; // Autoselect nearest track (unit = km)
const uint8_t gearOffset = 20; // Each gear has a corresponding value, this value define the interval (value - gearOffset < measure < value + gearOffset)
const uint8_t maxMlx = 6; // Max MLX chips that could be declared (could be more but need to add object instances L.300, just before setup())
const uint8_t mlxEepAddr = 0x0E; // Internal EEPROM address on MLX chips
const uint8_t firstMlxAddress = 0x01; // First given MLX I2C address (then +1 on each discovered MLX sensor)
const uint8_t maxHomepageScreens = 4; // The number of defined homepage screens

// GPS & Timing
const float rescaleGPS = 10000000.0; // We use "long" for GPS coordinates to keep precision ("float" on Arduino have only 6 decimal digits of precision) ### https://gis.stackexchange.com/questions/8650/measuring-accuracy-of-latitude-and-longitude

// GPS Configuration - General
const unsigned char ubxRate10Hz[] PROGMEM = {0x06, 0x08, 0x06, 0x00, 0x64, 0x00, 0x01, 0x00, 0x01, 0x00};
const unsigned char ubxTimepulse[] PROGMEM = {0x06, 0x31, 0x20, 0x00, 0x00, 0x01, 0x00, 0x00, 0x00, 0x00, 0x00, 0x00, 0x0A, 0x00, 0x00, 0x00, 0x01, 0x00, 0x00, 0x00, 0x00, 0x00, 0x00, 0x80, 0x00, 0x00, 0x00, 0x00, 0x00, 0x00, 0x00, 0x00, 0x29, 0x00, 0x00, 0x00};
//                                           |ID         |Lenght     |TP   |res  |res        |antCableD  |rfGrDelay  |freqPeriod             |freqPeriod lock        |Pulselenghtratio       |Pulselenghtratiolock   |UserConfigDelay        |Flags                 |
const unsigned char ubxPrtConf[] PROGMEM = {0x06, 0x00, 0x14, 0x00, 0x01, 0x00, 0x00, 0x00, 0xd0, 0x08, 0x00, 0x00, 0x00, 0xc2, 0x01, 0x00, 0x07, 0x00, 0x07, 0x00, 0x00, 0x00, 0x00, 0x00}; // 115200bps
//                                         |ID         |Lenght     |Port |res  |TX Ready   |mode                   |baudrate               |inPrMask   |outPrMask  |flags      |res       |

// GPS Configuration - Enable/disable specific NMEA sentences
const unsigned char ubxEnableRMC[] PROGMEM = {0x06, 0x01, 0x08, 0x00, 0xF0, 0x04, 0x00, 0x01, 0x00, 0x00, 0x00, 0x00};
const unsigned char ubxDisableGLL[] PROGMEM = {0x06, 0x01, 0x08, 0x00, 0xF0, 0x01, 0x00, 0x00, 0x00, 0x00, 0x00, 0x00};
const unsigned char ubxDisableGSA[] PROGMEM = {0x06, 0x01, 0x08, 0x00, 0xF0, 0x02, 0x00, 0x00, 0x00, 0x00, 0x00, 0x00};
const unsigned char ubxDisableGSV[] PROGMEM = {0x06, 0x01, 0x08, 0x00, 0xF0, 0x03, 0x00, 0x00, 0x00, 0x00, 0x00, 0x00};
const unsigned char ubxDisableVTG[] PROGMEM = {0x06, 0x01, 0x08, 0x00, 0xF0, 0x05, 0x00, 0x00, 0x00, 0x00, 0x00, 0x00};
const unsigned char ubxDisableZDA[] PROGMEM = {0x06, 0x01, 0x08, 0x00, 0xF0, 0x08, 0x00, 0x00, 0x00, 0x00, 0x00, 0x00};

// GPS Configuration - Backup configuration to non volatile memory
// const unsigned char ubxSave[] PROGMEM = {0x06, 0x09, 0x0D, 0x00, 0x00, 0x00, 0x00, 0x00, 0xFF, 0xFF, 0x00, 0x00, 0x00, 0x00, 0x01}; // No EEPROM => Backup battery
static NMEAGPS  gps;
static gps_fix  fix_data;
static gps_fix  fix_data_prev;

// Set these values to the offset of your timezone from GMT
static const int32_t          zone_hours   = +1L; // EST
static const int32_t          zone_minutes =  0L; // usually zero
static const NeoGPS::clock_t  zone_offset  = zone_hours * NeoGPS::SECONDS_PER_HOUR + zone_minutes * NeoGPS::SECONDS_PER_MINUTE;
#define EU_DST
#if defined(EU_DST)
static const uint8_t springMonth =  3;
static const uint8_t springDate  = 31; // latest last Sunday
static const uint8_t springHour  =  1;
static const uint8_t fallMonth   = 10;
static const uint8_t fallDate    = 31; // latest last Sunday
static const uint8_t fallHour    =  1;
#define CALCULATE_DST
#endif

// Texts
const static char ERROR_PROVIDE_NUMBER[] PROGMEM = "Error : you have to provide a number !";
char *inputsLabel[] = {"DIGI_SQR_RPM", "DIGI_SQR_OPT_1", "DIGI_BRAKE", "DIGI_OPT_1", "ANA_GEAR", "ANA_THROTTLE", "ANA_OPT_1", "ANA_OPT_2"};
char *inputsSexyLabel[] = {"RPM", "SQR_OPT", "BRAKE", "D_OPT1", "GEAR", "THROTTLE", "A_OPT1", "A_OPT2"};

// 9-Axis slave module (I2C)
#define I2C_SLAVE_ADDRESS 18 // I2C slave address

/**************************************************************
  #############################################
  ############## Vars definition ##############
  #############################################
**************************************************************/

// Inputs
uint32_t inDigiSqrRpm; // Digital square input (RPM)
uint32_t inDigiSqrOpt1; // Digital square input (optional)
bool inDigiBrake; // Digital boolean input (brake)
bool inDigiOpt1; // Digital boolean input (optional)
uint16_t inAnaGear; // Digital analog input (GEAR)
uint16_t inAnaThrottle; // Digital analog input (THROTTLE)
uint16_t inAnaOpt1; // Digital analog input (optional)
uint16_t inAnaOpt2; // Digital analog input (optional)
uint8_t enabledInputsBits; // Store enabled inputs (use binary values, ex : 11000000 > inAnaOpt1 and inAnaOpt2 enabled)
// BIT 0 = DIGI_SQR_RPM
// BIT 1 = DIGI_SQR_OPT_1
// BIT 2 = DIGI_BRAKE
// BIT 3 = DIGI_OPT_1
// BIT 4 = ANA_GEAR
// BIT 5 = ANA_THROTTLE
// BIT 6 = ANA_OPT_1
// BIT 7 = ANA_OPT_2
uint8_t tmpComp, bitShift; // Used to compare values for enabled inputs checks
char gear; // Store GEAR name (N, 1, 2, 3 ...)
uint16_t inAnaGearCalib[7]; // Calibration values for GEAR input
uint16_t inAnaThrottleMax, inAnaOpt1Max, inAnaOpt2Max; // Max values for analog inputs calibration
uint8_t gearNCheck = 0;

// SD Card
File logFile; // One line every 100ms with all detailed data
File lapFile; // One line per lap with laptime
File trackFile; // One line per track with GPS coordinates of finish line
File historyFile; // History of all sessions
char filename[32];
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
void loop() {
#ifdef DEBUG
  // Here we calculate average update rate of main loop
  Now = micros();
  deltat = ((Now - lastUpdate) / 1000000.0f);
  lastUpdate = Now;
  sum += deltat;
  sumCount++;
#endif

  /**************************************************************
    MCP1/Buttons interrupt
  **************************************************************/
  if (mcp1Interrupt) {
    handleMcp1Interrupt();
  }

  /**************************************************************
    Action on start/stop button
  **************************************************************/
  if (buttonPressed > 0 && mcp1PinTriggeredId == 3 && mcp1PinTriggeredState == 1 && showScreenId < 10) { // Call menu (short press on button "MENU" from home screen)
    buttonPressed = 0;
    showScreenId = 10;
    ms.display();
  }

  if (buttonPressed > 0 && mcp1PinTriggeredId == 1 && mcp1PinTriggeredState == 1 && showScreenId > 10) { // Back to menu (short press on button "BACK")
    if (showScreenId == 100) { // If laptimer is running we stop it ("STOP" button pressed when laptimer running)
      stopLaptimer();
    }
    buttonPressed = 0;
    showScreenId = 10;
    ms.display();
  }

  if (buttonPressed > 0 && mcp1PinTriggeredId == 1 && mcp1PinTriggeredState == 1 && showScreenId < 10) { // Switch homepage screen
    buttonPressed = 0;
    showScreenId++;
    if (showScreenId > maxHomepageScreens - 1) {
      showScreenId = 0;
    }
    ms.display();
  }

  /**************************************************************
    Get GPS frames through serial port (RX/TX)
    This is CRITICAL, data could be sent at any moment by the GPS so main loop should be executed in a minimum of time
    More information : https://github.com/SlashDevin/NeoGPS/blob/master/extras/doc/Troubleshooting.md#quiet-time-interval
  **************************************************************/
  if (gps.available(GPS_PORT)) {
    /**************************************************************
      Read last available GPS data
    **************************************************************/
    fix_data_prev = fix_data; // Memorize previous values before next GPS fix
    fix_data = gps.read(); // Get GPS data
    adjustTime( fix_data.dateTime );
    fixCount++;

    /**************************************************************
      Read 9-axis slave module
    **************************************************************/
    Wire.requestFrom(I2C_SLAVE_ADDRESS, 16); // Read 16 bytes (4 floats) from slave 9-axis sensor device
    while (Wire.available()) {
      for (int i = 0; i < 4; i++) {
        Wire.readBytes((byte*)&floatReceived, 4);
        mpuOrientation[i] = floatReceived; // Store values in array to use them later
      }
    }

    /**************************************************************
      Read all enabled INPUTS
    **************************************************************/
    elapsedTime = millis() - lastPinRead; // Used to have precise measures on RPM and SPEED
    lastPinRead = millis(); // Reset last pin read
    bitShift = B00000001;
    for (uint8_t i = 0; i < 8; i++) {  // Read values of enabled inputs only
      tmpComp = bitShift & enabledInputsBits;
      if (tmpComp == bitShift) {
        switch (i) {
          // bit 0 : inDigiSqrRpm;
          case 0:
            REG_TCC1_CTRLBSET = TCC_CTRLBSET_CMD_READSYNC;  // Trigger a read synchronization on the COUNT register
            while (TCC1->SYNCBUSY.bit.CTRLB);               // Wait for the CTRLB register write synchronization
            while (TCC1->SYNCBUSY.bit.COUNT);               // Wait for the COUNT register read sychronization
            inDigiSqrRpm = REG_TCC1_COUNT;                       // Read TCNT1 register (timer1 counter)
            REG_TCC1_COUNT = 0x0000;                        // Clear timer's COUNT value
            while (TCC1->SYNCBUSY.bit.COUNT);               // Wait for synchronization
            inDigiSqrRpm = inDigiSqrRpm * rpmCorrectionRatio * 600 / elapsedTime / rpmFlywheelTeeth; // Ratio between pulse and rpm (22 > flywheel has 22 teeth ### 600 > with check every 100ms, RPM is by minute) ### rpmCorrectionRatio > *(100+corr) / elapsedTime) > if we read counter @101ms or 102ms values should be adjusted
            break;
          // bit 1 : inDigiSqrOpt1;
          case 1:
            REG_TCC0_CTRLBSET = TCC_CTRLBSET_CMD_READSYNC;  // Trigger a read synchronization on the COUNT register
            while (TCC0->SYNCBUSY.bit.CTRLB);               // Wait for the CTRLB register write synchronization
            while (TCC0->SYNCBUSY.bit.COUNT);               // Wait for the COUNT register read sychronization
            inDigiSqrOpt1 = REG_TCC0_COUNT;                     // Read TCNT0 register (timer0 counter)
            REG_TCC0_COUNT = 0x0000;                        // Clear timer's COUNT value
            while (TCC0->SYNCBUSY.bit.COUNT);               // Wait for synchronization
            inDigiSqrOpt1 = inDigiSqrOpt1 * 100 / elapsedTime; // Ratio is set to 1 so no maths ### (* 100 / elapsedTime) > if we read counter @99ms, 101ms or 102ms values should be adjusted
            break;
          // bit 2 : inDigiBrake;
          case 2:
            inDigiBrake = digitalRead(inDigiBrakePin); // Read "inDigiBrakePin" (pin is plugged on the "+" of the stop light)
            break;
          // bit 3 : inDigiOpt1;
          case 3:
            inDigiOpt1 = digitalRead(inDigiOpt1Pin); // Read "inDigiOpt1Pin"
            break;
          // bit 4 : inAnaGear;
          case 4:
            inAnaGear = constrain(analogRead(inAnaGearPin), 0, 1024);
            if (inAnaGear <= inAnaGearCalib[1] + gearOffset) {
              gear = '1';
            }
            if (inAnaGear > inAnaGearCalib[2] - gearOffset && inAnaGear <= inAnaGearCalib[2] + gearOffset) {
              gear = '2';
            }
            if (inAnaGear > inAnaGearCalib[3] - gearOffset && inAnaGear <= inAnaGearCalib[3] + gearOffset) {
              gear = '3';
            }
            if (inAnaGear > inAnaGearCalib[4] - gearOffset && inAnaGear <= inAnaGearCalib[4] + gearOffset) {
              gear = '4';
            }
            if (inAnaGear > inAnaGearCalib[5] - gearOffset && inAnaGear <= inAnaGearCalib[5] + gearOffset) {
              gear = '5';
            }
            if (inAnaGear > inAnaGearCalib[6] - gearOffset && inAnaGear <= inAnaGearCalib[6] + gearOffset) {
              gear = '6';
            }
            if (inAnaGear > inAnaGearCalib[0] - gearOffset && inAnaGear <= inAnaGearCalib[0] + gearOffset) {
              if (gearNCheck > 3) { // We test 3 times to prevent displaying "N" between 2 gears
                gear = 'N';
              } else {
                gearNCheck++;
              }
            } else {
              gearNCheck = 0;
            }
            break;
          // bit 5 : inAnaThrottle;
          case 5:
            inAnaThrottle = constrain(map(analogRead(inAnaThrottlePin), 0, inAnaThrottleMax, 0, 100), 0, 100);
            break;
          // bit 6 : inAnaOpt1;
          case 6:
            inAnaOpt1 = constrain(map(analogRead(inAnaOpt1Pin), 0, inAnaOpt1Max, 0, 100), 0, 100);
            break;
          // bit 7 : inAnaOpt2;
          case 7:
            inAnaOpt2 = constrain(map(analogRead(inAnaOpt2Pin), 0, inAnaOpt2Max, 0, 100), 0, 100);
            break;
        }
      }
      bitShift = bitShift << 1;
    }

    /**************************************************************
      Print data on OLED screen
    **************************************************************/
    showData(showScreenId); // 0 = Home, 10 = menu navigation, 11 to 254 = menu actions

    /**************************************************************
      Sync files on SDcard every 300 fixes (300x100ms = 30sec) to avoid dataloss on power failure
    **************************************************************/
    if (isRunning && (fixCount - lastSdSync >= 300)) {
      lastSdSync = fixCount;
      SdFile::dateTimeCallback(dateTimeSd);
      logFile.sync();
      lapFile.sync();
    }

    /**************************************************************
      1 second loop (every 10 fixes > 10x100ms = 1sec), could be used for :
      - Get values with a low refresh rate like ambiant temperature
      - Printing debug information
      - ...
    **************************************************************/
    if (fixCount - lastLCDupdate >= 10) {
      lastLCDupdate = fixCount;
#ifdef DEBUG
      DEBUG_PORT.print("rate = ");
      DEBUG_PORT.print((float)sumCount / sum, 2);
      DEBUG_PORT.println(" Hz");
      sumCount = 0;
      sum = 0;
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

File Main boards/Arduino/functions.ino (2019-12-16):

/**************************************************************
  #stopLaptimer > Stop laptimer
**************************************************************/
void stopLaptimer() {
  SdFile::dateTimeCallback(dateTimeSd);
  isRunning = false; // ... we stop recording
  logFile.close(); // Close file on SDcard
  lapFile.close(); // Close file on SDcard
  OLED_PORT.clear();
  BLUETOOTH_PORT.println(F("[Session stopped !]"));
}

/**************************************************************
  #startLaptimer > Start laptimer (init multiple var, auto select nearest track, create files on SD card)
**************************************************************/
void startLaptimer() {
  SdFile::dateTimeCallback(dateTimeSd);
  if (fix_data.valid.location) { // We need GPS fix before starting
    OLED_PORT.clear();
    OLED_PORT.println(F("Auto-select track ..."));
    BLUETOOTH_PORT.println(F("[Start new session !]"));

    /**************************************************************
      Select nearest track from the file "TRACKS.csv" on sdcard
    **************************************************************/
    recordTrackData = false;
    trackFile = sd.open("TRACKS.csv", FILE_READ);
    if (trackFile) {
      while (trackFile.available()) {
        csvReadUint16(&trackFile, &trackId, csvDelim);
        csvReadText(&trackFile, trackName, sizeof(trackName), csvDelim); // One line per track : "1;CAROLE;489799930;25224350;489800230;25226330" (<trackname>;<startline_a_lat>;<startline_a_lon>;<startline_b_lat>;<startline_b_lon>)
        csvReadInt32(&trackFile, &flineLat1, csvDelim);                  // Points A & B should be at the left and at the right of the finishline (a few meters)
        csvReadInt32(&trackFile, &flineLon1, csvDelim);
        csvReadInt32(&trackFile, &flineLat2, csvDelim);
        csvReadInt32(&trackFile, &flineLon2, csvDelim);

        // Calculate distance between 2 GPS coordinates
        coordsDistance = gpsDistance(fix_data.latitudeL(), fix_data.longitudeL(), flineLat1, flineLon1) / 1000;

        // If you are on a known track, then we select it
        if (coordsDistance <= maxTrackDistance) {
          recordTrackData = true;
          OLED_PORT.print(trackName);
          OLED_PORT.print(F(" ("));
          OLED_PORT.print(coordsDistance, 1);
          OLED_PORT.println(F("km)"));
          BLUETOOTH_PORT.print(F("Track selected : "));
          BLUETOOTH_PORT.print(trackName);
          BLUETOOTH_PORT.print(F(" ("));
          BLUETOOTH_PORT.print(coordsDistance, 1);
          BLUETOOTH_PORT.println(F("km)"));
          break; // Break here so last read values are the good ones !
        }
      }
      trackFile.close();
    }
    if (recordTrackData == false) {
      OLED_PORT.println(F("No track file !"));
      BLUETOOTH_PORT.println(F("No track file !"));
    }

    /**************************************************************
      Create new datafile : history file (append)
    **************************************************************/
    if (recordTrackData == true) { // No track = no history !
      sprintf(filename, "HISTORY.csv");
      if (historyFile.open(filename, O_CREAT | O_APPEND | O_WRITE)) {
        historyFile.print(fix_data.dateTime);
        historyFile.print(F(";"));
        historyFile.print(fix_data.dateTime.year);
        if (fix_data.dateTime.month < 10) historyFile.print(F("0")); // Leading zeros
        historyFile.print(fix_data.dateTime.month);
        if (fix_data.dateTime.date < 10) historyFile.print(F("0")); // Leading zeros
        historyFile.print(fix_data.dateTime.date);
        historyFile.print(F("-"));
        if (fix_data.dateTime.hours < 10) historyFile.print(F("0")); // Leading zeros
        historyFile.print(fix_data.dateTime.hours);
        if (fix_data.dateTime.minutes < 10) historyFile.print(F("0")); // Leading zeros
        historyFile.print(fix_data.dateTime.minutes);
        if (fix_data.dateTime.seconds < 10) historyFile.print(F("0")); // Leading zeros
        historyFile.print(fix_data.dateTime.seconds);
        historyFile.print(F(";"));
        historyFile.println(trackId);
        historyFile.close(); // Close file on SDcard
        BLUETOOTH_PORT.print(F("Append file : "));
        BLUETOOTH_PORT.println(filename);
      } else {
        initError();
      }
    }

    /**************************************************************
      Create new datafile : log file (create new)
    **************************************************************/
    sprintf(filename, "%02u%02u%02u-%02u%02u%02u.csv", fix_data.dateTime.year, fix_data.dateTime.month, fix_data.dateTime.date, fix_data.dateTime.hours, fix_data.dateTime.minutes, fix_data.dateTime.seconds);
    if (logFile.open(filename, O_CREAT | O_WRITE | O_EXCL)) {
      // Time, distance and lap (always printed)
      logFile.print(F("Time;Distance;Lap;"));

      // Digital & analog inputs (printed if enabled)
      bitShift = B00000001;
      for (uint8_t i = 0; i < 8; i++) {
        tmpComp = bitShift & enabledInputsBits;
        if (tmpComp == bitShift) {
          logFile.print(inputsLabel[i]);
          logFile.print(F(";"));
        }
        bitShift = bitShift << 1;
      }

      // KPH (GPS), Orientation, ambiant temperature (always printed)
      logFile.print(F("KPH;Heading;Roll;Pitch;"));

      // Infrared temperature (printed if enabled)
      for (uint8_t i = 0; i < maxMlx; i++) {
        if (mlxAddresses[i] != 0x00) {
          logFile.print(F("IRTemp"));
          logFile.print(i);
          logFile.print(F(";"));
        }
      }

      // Latitude & longitude (always printed)
      logFile.println(F("Latitude;Longitude"));
      BLUETOOTH_PORT.print(F("Create new file : "));
      BLUETOOTH_PORT.println(filename);
    } else {
      initError();
    }

    /**************************************************************
      Create new datafile : laptime file (create new)
    **************************************************************/
    sprintf(filename, "%02u%02u%02u-%02u%02u%02u-LAPTIMES.csv", fix_data.dateTime.year, fix_data.dateTime.month, fix_data.dateTime.date, fix_data.dateTime.hours, fix_data.dateTime.minutes, fix_data.dateTime.seconds);
    if (lapFile.open(filename, O_CREAT | O_WRITE | O_EXCL)) {
      BLUETOOTH_PORT.print(F("Create new file : "));
      BLUETOOTH_PORT.println(filename);
    } else {
      initError();
    }

    /**************************************************************
      Init some vars
    **************************************************************/
    isRunning = true; // ... we start recording
    lapCounter = 0; // Lap 0 (we start from paddocks)
    totalDistance = 0;
    addFinishLog = false;
  }
}
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

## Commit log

2019-07-15 DAWA 6.1
    Initial release
    [DAWA 6.1-ENCLOSURE.f3d, DAWA 6.1-ENCLOSURE1.stl, DAWA 6.1-ENCLOSURE2.stl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]
2019-07-22 Add prices
    [Partslist-v6.1.xlsx]
2020-11-03 Add PDF schematics

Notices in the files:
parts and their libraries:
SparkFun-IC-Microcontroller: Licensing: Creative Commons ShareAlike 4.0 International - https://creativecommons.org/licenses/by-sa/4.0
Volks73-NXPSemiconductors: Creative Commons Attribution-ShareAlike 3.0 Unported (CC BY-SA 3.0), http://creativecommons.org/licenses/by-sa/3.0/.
